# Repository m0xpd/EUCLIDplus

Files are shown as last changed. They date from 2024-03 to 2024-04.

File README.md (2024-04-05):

# EUCLID+
EUCLID+ is a novel Clock Divider, Clock Multiplier and Rhythm Sequencer for electronic music applications. 

<p width=100%, align="center">
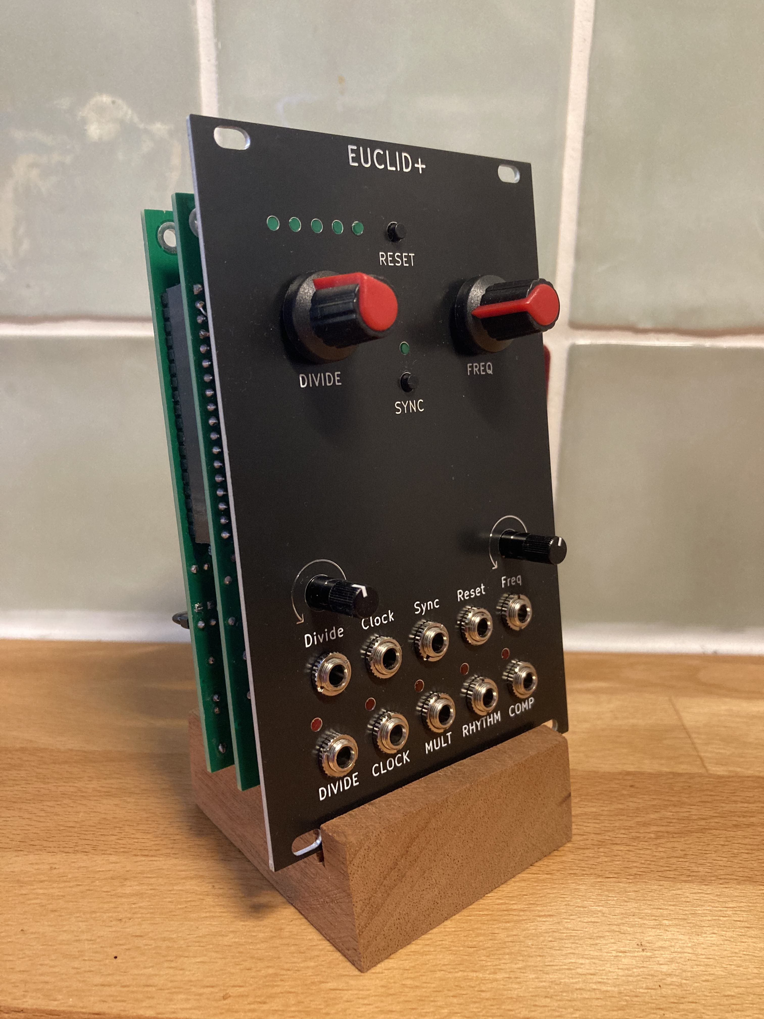
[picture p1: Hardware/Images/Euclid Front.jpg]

</p>

EUCLID+ builds gate patterns, including [Euclidean Rhythms.](https://en.wikipedia.org/wiki/Euclidean_rhythm) Unlike most instances of Euclidean Rhythms, which are generated by algorithms, EUCLID+ is realised entirely in hardware and builds its patterns using what I shall call [conditional modulation](https://github.com/m0xpd/EUCLIDplus/tree/main/Operation#readme) of an external clock signal by the signal from an oscillator internal to EUCLID+.

Strictly speaking, EUCLID+ *usually* produces a *rotation* of a Euclidean Rhythm (which is an instance of the same '[rhythm necklace](https://cgm.cs.mcgill.ca/~godfried/publications/banff.pdf)' as the Euclidean Rhythm). EUCLID+ *occasionally* produces a Euclidean Rhythm.

If you're looking for a module where you just dial in parameters and out pops a Euclidean Rhythm, this isn't for you. However, if you're interested in working with a creative platform on which you can explore possibilities in rhythm generation, and are open to the surprises which you meet along the way, EUCLID+ might be of interest. 

Here's a 'scope trace of EUCLID+ producing the [tresillo](https://en.wikipedia.org/wiki/Tresillo_(rhythm)) (or habanera) rhythm, which is Euclidean Rhythm "*E*(3,8)" (= [10010010] or, as more frequently represented in the notation used in musicology, [x..x..x.]).

<p width=100%, align="center">
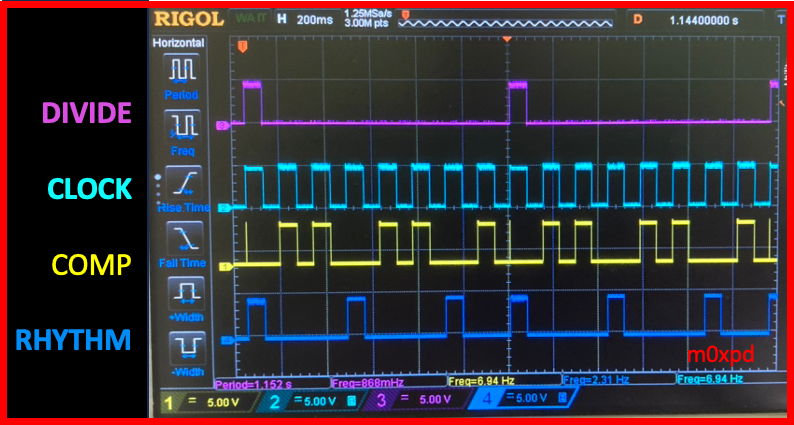
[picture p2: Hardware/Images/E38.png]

</p>

There are more examples of EUCLID+ performance [here](https://github.com/m0xpd/EUCLIDplus/blob/main/Operation/README.md#performance-examples).

EUCLID+ divides an applied clock signal by any integer divisor up to 30, making EUCLID+ useful as a voltage-controlled hardware clock divider. The start of the clock divide cycle can be reset manually, using the RESET pushbutton, or under CV control via the Reset input.

EUCLID+ includes an integral VCO, operating in the LFO range, which can serve as a voltage controlled clock multiplier. Signals from the clock divider and clock multiplier are available for external use on the DIVIDE and MULT outputs. 

EUCLID+ combines the clock input and the signal from the clock multiplier to provide gate patterns on the RHYTHM output. The complements of these patterns appear on the COMP output. The duty cycle of the RHYTHM and COMP outputs follows that of the input Clock waveform.

EUCLID+ can hard-sync its VCO to the clock divider output. In this condition, the output pattern is fixed, having the same period as the clock divider. The patterns in this synchronous mode include the familiar [Euclidean Rhythms](https://en.wikipedia.org/wiki/Euclidean_rhythm) (of length up to 30). Note that [the complement of a Euclidean Rhythm is itself Euclidean](https://www.researchgate.net/publication/228841028_Interlocking_and_Euclidean_rhythms); the COMP output produces musically useful triggers for primary voices in complementary and interlocking rhythmic structures as well as for producing "ghost notes".

Alternatively, the VCO inside EUCLID+ can run asynchronously to the applied clock, giving the resulting pattern outputs a useful varying quality, but one which retains much of the structure (/correlation/'feel') of the behaviour in synchronous mode. Careful tuning of the VCO in asynchronous mode can exploit this variation to impart slow, organic change into what can otherwise be a dry, sterile, mechanistic process.

Switching between synchronous and asynchronous operation can be achieved manually, using the SYNC pushbutton, or under CV control via the Sync input.

There is a fuller description of the principles behind EUCLID+ operation [here](https://github.com/m0xpd/EUCLIDplus/tree/main/Operation#readme) and a detailed description of circuit operation [here](https://github.com/m0xpd/EUCLIDplus/tree/main/Operation#circuit-description).

The Clock Divider's DIVIDE setting is reported on five LEDs at the top left of the front panel. There are two idosyncracies of this display worth explaining. 

First, the binary display is arranged with least significant bit on the left, which (of course) is opposite to ordinary practice. This reversal was adopted as it made the display more 'natural' in use, given its placement immediately above the DIVIDE potentiometer, which generates an increasing value as it is rotated clockwise. 

Second, as explained in the [description of system operation](https://github.com/m0xpd/EUCLIDplus/tree/main/Operation#readme), the binary number on the display must be set to one greater than the desired clock divisor. In other words, to achieve a clock division of 8, you must set the number 9 (1,0,0,1) on the LEDs.  

Full design details for EUCLID+ including schematics, PCB layouts for the [Main Board](https://github.com/m0xpd/EUCLIDplus/tree/main/Hardware/Main%20Board#readme) and [Control Board](https://github.com/m0xpd/EUCLIDplus/tree/main/Hardware/Control%20Board#readme) and a [Front Panel](https://github.com/m0xpd/EUCLIDplus/tree/main/Hardware/Front%20Panel#readme) design, are presented in the hardware folder.  

For those who are discouraged by the complexity of the hardware approach - or those who would simply like to play with the rhythm generation method used in EUCLID+ in a context which avoids oscillator drift and the other non-ideal behaviours associated with hardware - a software implementation of EUCLID+ is presented [here](https://github.com/m0xpd/EUCLIDplus/tree/main/Software%20Version#readme)

# Introductory Video

A [simple video](https://youtu.be/RWJx1ux7fJk) demonstrates some of the basic functionalty of EUCLID+

# License

EUCLID+ (including the descriptions of its operating principles, and the hardware and software embodiments described in this repository) is published under [CC BY-SA 4.0 License](https://github.com/m0xpd/EUCLIDplus/blob/main/LICENSE.txt).

# Specifications

**Width:** 

EUCLID+ is **16HP wide**.

**Depth:**

EUCLID+ extends **43 mm** behind the front panel when a conventional Eurorack power header **with strain relief** is inserted 

If your power header doesn't have a strain relief (which is probably more typical, judging by the power cables delivered with commercial modules) EUCLID+ extends **37 mm** behind the front panel.

**Power Consumption:**

| Power Rail | Current |
|---|---|
| +12V | **30mA** | 
| -12V | **15mA** |
| 5V | **0** |

The 12V current drain was fluctuating during measurement (with the module's switching behaviour during operation and during operation of the controls); the 30mA figure quoted above is an 'eyeball estimate' of average current - the peak drain observed was 35mA.
The -12V current drain was steady; 15mA is the average consumption.

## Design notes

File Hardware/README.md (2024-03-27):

# Hardware
This folder contains details of the hardware of the Euclid+ Rhythm Generator.

There is a [Front Panel](https://github.com/m0xpd/EUCLIDplus/tree/main/Hardware/Front%20Panel#readme), Defined by a KiCad project, and two PCBs - the [Main Board](https://github.com/m0xpd/EUCLIDplus/tree/main/Hardware/Main%20Board#readme) and the [Control Board](https://github.com/m0xpd/EUCLIDplus/tree/main/Hardware/Control%20Board#readme).

Schematics for the boards, as graphics, are presented in the [circuit description](https://github.com/m0xpd/EUCLIDplus/tree/main/Operation#readme) (and are available within the KiCad projects).

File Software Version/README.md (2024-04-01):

# EUCLID+ in Software

This folder describes a software implementation of the principles behind EUCLID+

There is a basic coding of the EUCLID+ method in Python [here](https://github.com/m0xpd/EUCLIDplus/blob/main/Software%20Version/EuclidPlus.py), intended to run on the [Raspberry Pi PICO](https://www.raspberrypi.com/products/raspberry-pi-pico/). It could easily be ported to other RPi-based platforms, such as [EuroPi](https://allensynthesis.co.uk/modules/europi.html). 

The code certainly isn't pretty - I hacked it from a Ratcheting clock multiplier application I had been playing with, so many of the variable names and the overall structure didn't start on a blank canvas, which would have been better practice. However, it does the job.

I have also sketched a partial KiCad project showing how the code could be supported by hardware which could easily be elaborated into a module. Most importantly, there's a [.sch file](https://github.com/m0xpd/EUCLIDplus/blob/main/Software%20Version/Platform/EuclidPlusPi.kicad_sch) and a (graphical) schematic...

<p width=100%, align="center">

</p>

The code and hardware were validated at breadboard level on a simple system, shown below:

<p width=100%, align="center">
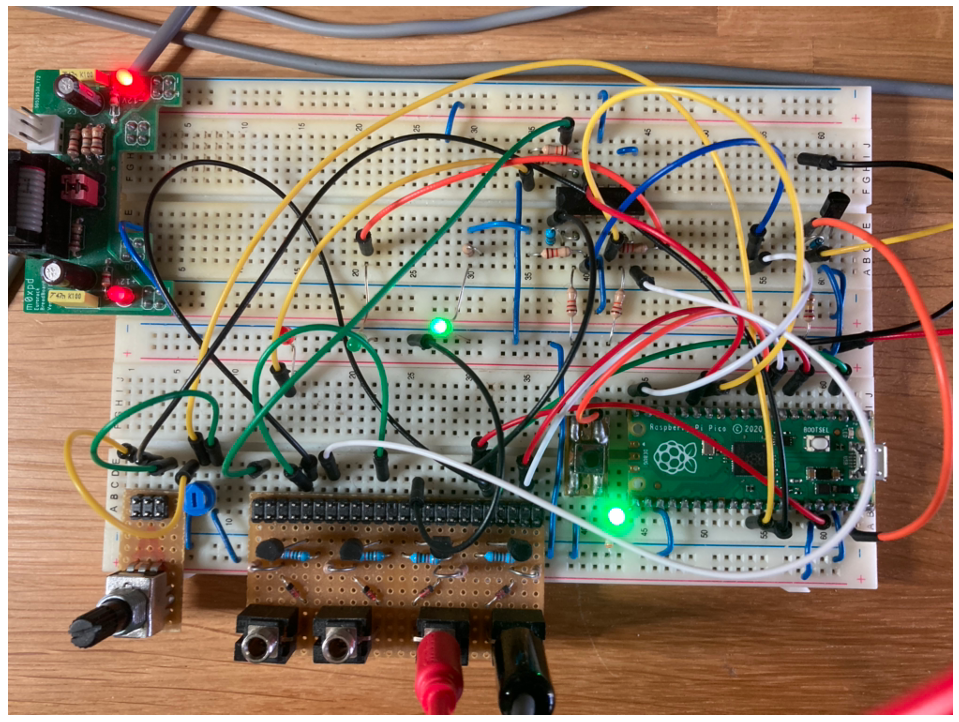
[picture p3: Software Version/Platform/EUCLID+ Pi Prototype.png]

</p>

The example system and its circuitry include only manual controls (for clock division, internal oscillator frequency, etc) with no provision for Voltage Control. CV inputs could readily be included using standard methods, such as those used in the EUCLID+ module, appropriately adapted for the (0:3V3) operating range of the RPi.

The pin allocation for the RPi is shown below:

<p width=100%, align="center">
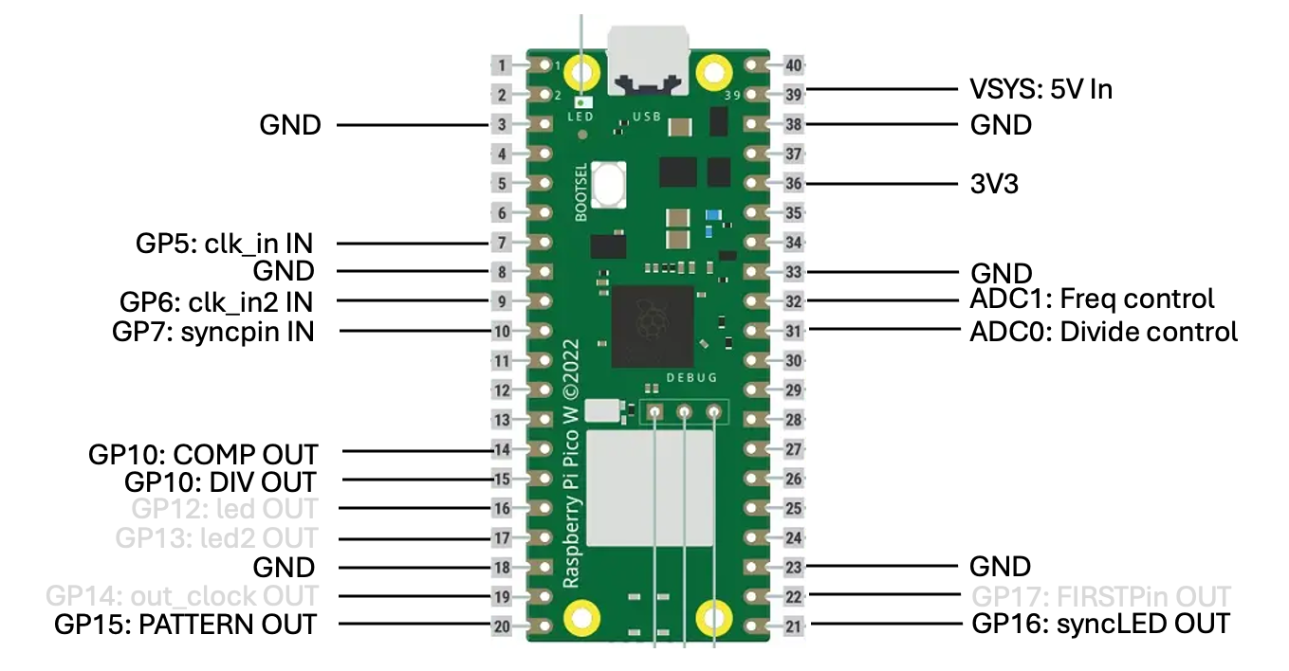
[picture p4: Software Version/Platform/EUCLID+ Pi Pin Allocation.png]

</p>

Notice that I originally named the main 'RHYTHM' output of EUCLID+ 'PATTERN'. Apologies for this (and any other) notational anomaly.

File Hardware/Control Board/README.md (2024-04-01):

# Control Board
This folder contains details of the EUCLID+ Control Board.

<p width=100%, align="center">
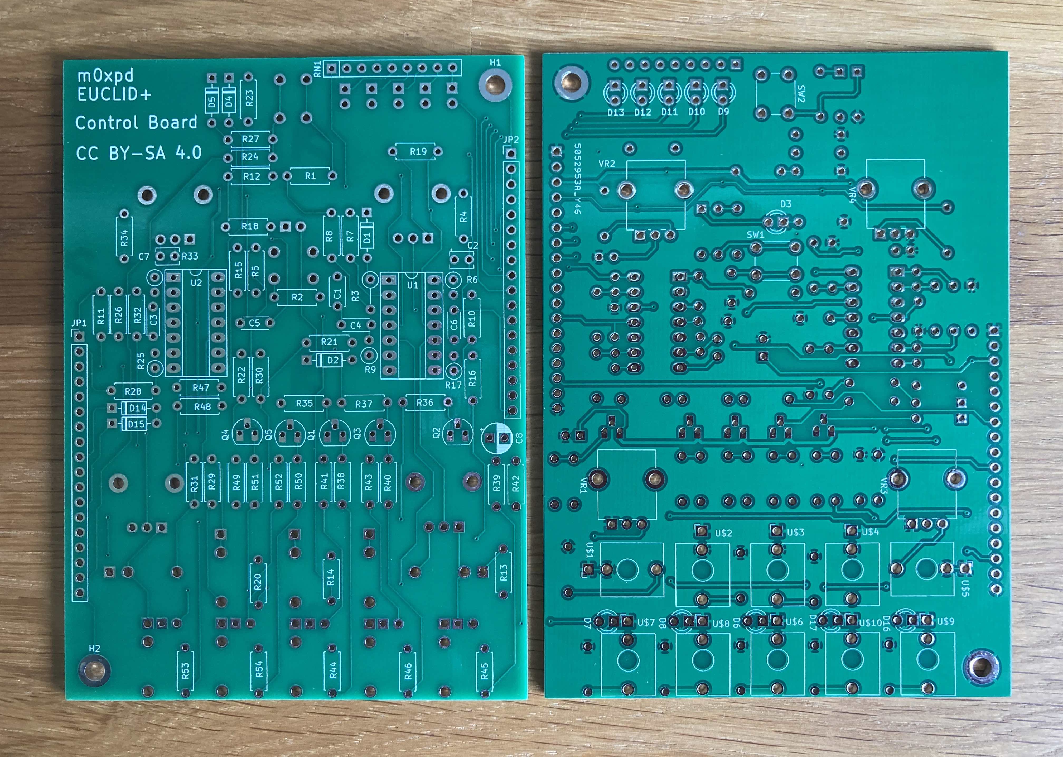
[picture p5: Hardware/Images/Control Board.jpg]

</p>

[This is actually a photo of the v1 Control Board. This earlier version had a different slightly footprint for C8, which is now a radial electrolytic. Also, some of the PCB tracks carrying power on the v2 version are thicker than on the V1 version, which is archived in the [v1 Control Board](https://github.com/m0xpd/EUCLIDplus/tree/main/Hardware/Control%20Board/v1%20Control%20Board) folder]

The populated (v1) Control Board is seen (from the top/component side) in the photo below. It is mounted to the [Front Panel](https://github.com/m0xpd/EUCLIDplus/tree/main/Hardware/Front%20Panel#readme) by the two (9mm Alpha) potentiometers and the ten ("Thonkiconn") sockets mounted on the bottom side.

<p width=100%, align="center">
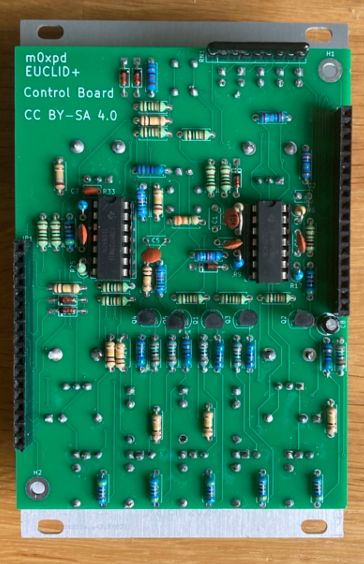
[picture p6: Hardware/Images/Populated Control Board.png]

</p>

Also visible in the image above are the two 1*18 0.1 inch headers which join the Main and Control boards electrically. These are female headers on the top of the Control Board, which mate with corresponding male headers on the bottom of the Main Board. These headers provide sufficient mechanical mounting of the two boards for 'static' applications, but there are provided two 3mm clearance mounting holes, H1 & H2, to make a more robust assembly with M3 screws and spacers, if required.

This folder contains a KiCad [Project File (.pro)](https://github.com/m0xpd/EUCLIDplus/blob/main/Hardware/Control%20Board/Euclid%2B%20Control%20Board.kicad_pro), a [Schematic File (.sch)](https://github.com/m0xpd/EUCLIDplus/blob/main/Hardware/Control%20Board/Euclid%2B%20Control%20Board.kicad_sch) and a [PCB file (.pcb)](https://github.com/m0xpd/EUCLIDplus/blob/main/Hardware/Control%20Board/Euclid%2B%20Control%20Board.kicad_pcb).

There is also a [BoM](https://github.com/m0xpd/EUCLIDplus/blob/main/Hardware/Control%20Board/Euclid%2B%20Control%20Board%20BoM.xlsx), which is an Excel file; you will have to download the raw file and view it outside github.

A version of the schematic in graphical (svg) format is available in the [Operation](https://github.com/m0xpd/EUCLIDplus/tree/main/Operation#readme) folder

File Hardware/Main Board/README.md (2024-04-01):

# Main Board
This folder contains details of the EUCLID+ Main Board.

<p width=100%, align="center">
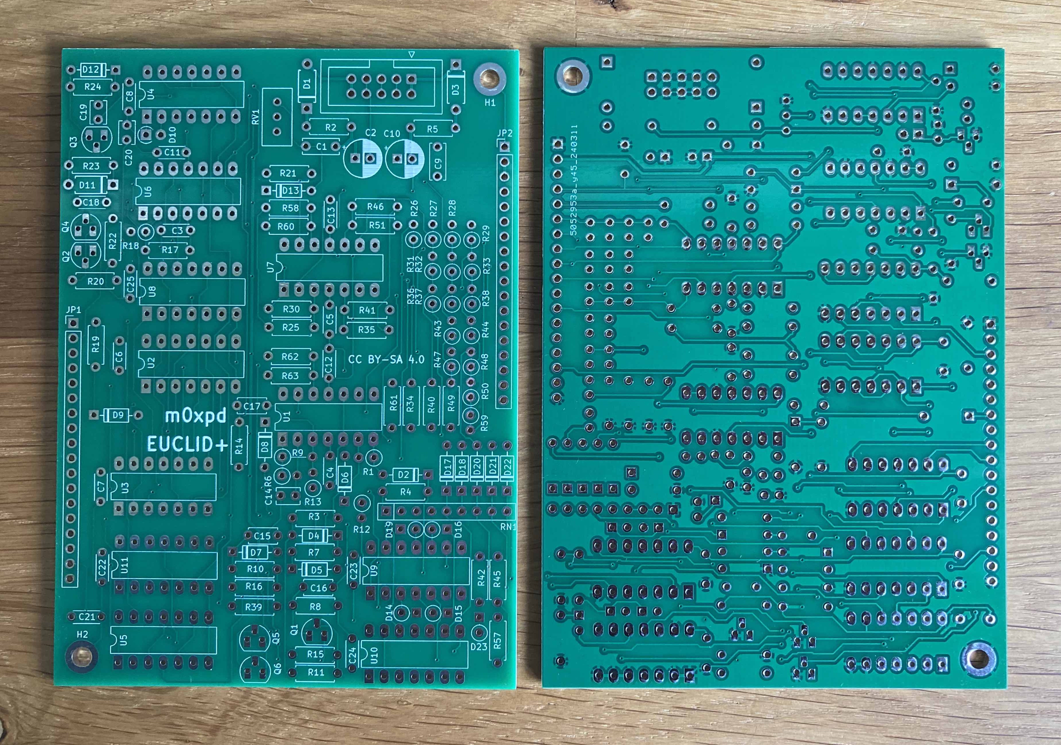
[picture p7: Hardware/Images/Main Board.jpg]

</p>

[This is actually a photo of the v1 Main Board, which had some errors on the bottom side - the project associated with this board is in the [v1 Main Board folder](https://github.com/m0xpd/EUCLIDplus/tree/main/Hardware/Main%20Board/v1%20Main%20Board) and the errors are indicated on the schematic. This v1 Main Board also does not include the footprint for C28, which was found necessary to avoid jitter on the internal oscillator signal's duty cycle.]

Here's the populated (v1) Main Board, seen from the component side:
<p width=100%, align="center">
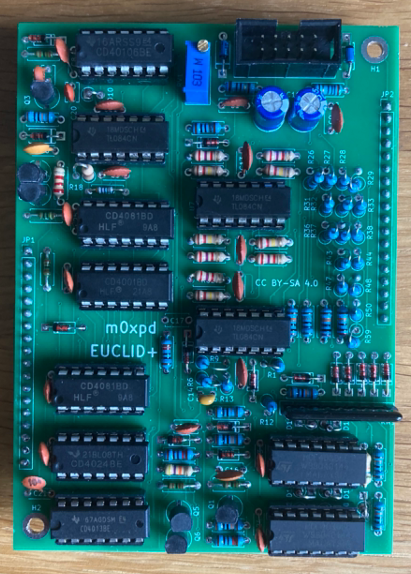
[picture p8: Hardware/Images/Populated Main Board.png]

</p>

The folder contains a KiCad [Project File (.pro)](https://github.com/m0xpd/EUCLIDplus/blob/main/Hardware/Main%20Board/Euclid%2B%20Main%20Board.kicad_pro), a [Schematic File (.sch)](https://github.com/m0xpd/EUCLIDplus/blob/main/Hardware/Main%20Board/Euclid%2B%20Main%20Board.kicad_sch) and a [PCB file (.pcb)](https://github.com/m0xpd/EUCLIDplus/blob/main/Hardware/Main%20Board/Euclid%2B%20Main%20Board.kicad_pcb).

There is also a [BoM](https://github.com/m0xpd/EUCLIDplus/blob/main/Hardware/Main%20Board/Euclid%2B%20Main%20Board%20BoM.xlsx) which is an Excel file; you will have to download the raw file and view it outside github. 

A version of the schematic in graphical (svg) format is available in the [Operation](https://github.com/m0xpd/EUCLIDplus/tree/main/Operation#readme) folder

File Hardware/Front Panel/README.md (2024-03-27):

# Front Panel
This folder contains details of the EUCLID+ Front Panel.

<p width=100%, align="center">
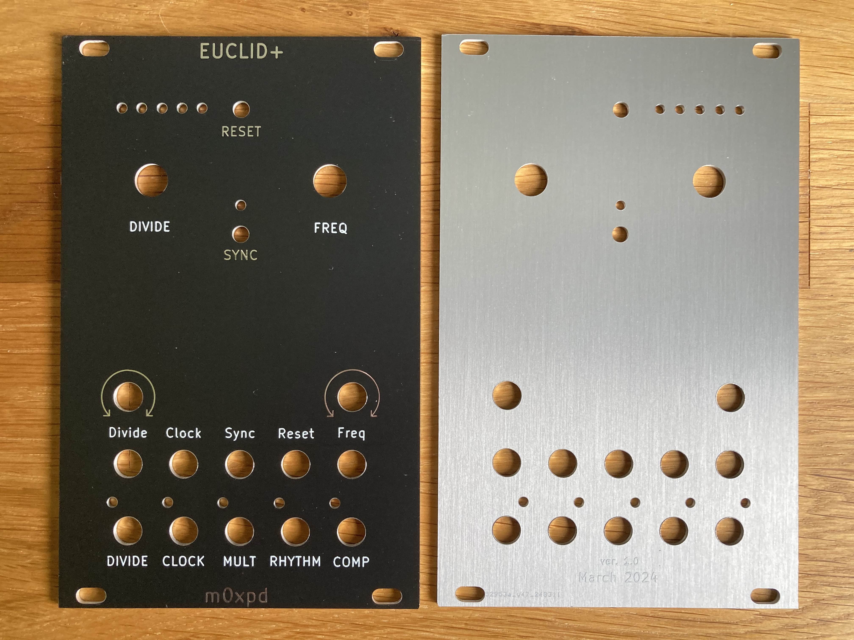
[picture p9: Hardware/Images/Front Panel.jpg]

</p>

There is a KiCad Project File (.pro), a Schematic File (.sch) - although this is empty, as the Front Panel is electrically inactive (it is required only to make a valid project). Most importantly, 
there is a PCB file (.pcb).

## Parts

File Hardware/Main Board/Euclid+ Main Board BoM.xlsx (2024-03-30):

Source: | /Users/pauldarlington/Documents/Analog Synth/Euclid/Euclid+ Main Board/Euclid+ Main Board.kicad_sch
Date: | Wednesday, March 27, 2024 at 01:09:04‚ÄØPM
Tool: | Eeschema 7.0.9
Generator: | /Applications/KiCad/KiCad.app/Contents/SharedSupport/plugins/bom_csv_grouped_by_value.py
Component Count: | 130
Collated Components:
Item | Qty | Reference(s) | Value | Orientation | LibPart | Footprint | Datasheet | DNP | Sim.Device | Sim.Pins
1 | 2 | C1, C9 | 0.1u |  | main board-eagle-import:C-EU050-025X075 | Capacitor_THT:C_Disc_D6.0mm_W2.5mm_P5.00mm
2 | 2 | C2, C10 | 22u |  | Device:C_Polarized | Capacitor_THT:CP_Radial_D6.3mm_P2.50mm | ~
3 | 14 | C3, C4, C5, C6, C7, C8, C11, C12, C13, C21, C22, C23, C24, C25 | 100n |  | Device:C | Capacitor_THT:C_Disc_D4.3mm_W1.9mm_P5.00mm | ~
4 | 4 | C14, C15, C16, C17 | 100n |  | Device:C | Capacitor_THT:C_Disc_D4.7mm_W2.5mm_P5.00mm | ~
5 | 1 | C18 | 2n2 |  | Device:C | Capacitor_THT:C_Disc_D4.3mm_W1.9mm_P5.00mm | ~
6 | 1 | C19 | 4n7 |  | Device:C | Capacitor_THT:C_Disc_D3.8mm_W2.6mm_P2.50mm | ~
7 | 1 | C20 | 10n |  | Device:C | Capacitor_THT:C_Disc_D3.8mm_W2.6mm_P2.50mm | ~
8 | 1 | C26 | 1u |  | Device:C | Capacitor_THT:CP_Radial_D6.3mm_P2.50mm
9 | 2 | D1, D3 | BAT42 | Horizontal | Device:D_Schottky_Small | Diode_THT:D_A-405_P7.62mm_Horizontal | ~
10 | 14 | D2, D4, D5, D6, D7, D8, D9, D12, D13, D17, D18, D20, D21, D22 | 1N4148 | Horizontal | Diode:1N4148 | Diode_THT:D_DO-35_SOD27_P7.62mm_Horizontal | https://assets.nexperia.com/documents/data-sheet/1N4148_1N4448.pdf |  | D | 1=K 2=A
11 | 1 | D10 | 1N4148 | Vertical | Diode:1N4148 | Diode_THT:D_A-405_P2.54mm_Vertical_AnodeUp | https://assets.nexperia.com/documents/data-sheet/1N4148_1N4448.pdf |  | D | 1=K 2=A
12 | 1 | D11 | 1N4148 | Horizontal | Diode:1N4148 | Diode_THT:D_A-405_P7.62mm_Horizontal | https://assets.nexperia.com/documents/data-sheet/1N4148_1N4448.pdf |  | D | 1=K 2=A
13 | 5 | D14, D15, D16, D19, D23 | 1N4148 | Vertical | Diode:1N4148 | Diode_THT:D_DO-35_SOD27_P2.54mm_Vertical_KathodeUp | https://assets.nexperia.com/documents/data-sheet/1N4148_1N4448.pdf |  | D | 1=K 2=A
14 | 2 | H1, H2 | MountingHole_Pad |  | Mechanical:MountingHole_Pad | MountingHole:MountingHole_3.2mm_M3_DIN965_Pad_TopBottom | ~
15 | 2 | JP1, JP2 | ~ |  | control board-eagle-import:PINHD-1X18 | Connector_PinHeader_2.54mm:PinHeader_1x18_P2.54mm_Vertical
16 | 5 | Q1, Q2, Q3, Q5, Q6 | BC546 |  | Transistor_BJT:BC546 | Package_TO_SOT_THT:TO-92_HandSolder | https://www.onsemi.com/pub/Collateral/BC550-D.pdf
17 | 1 | Q4 | BC556 |  | Transistor_BJT:BC556 | Package_TO_SOT_THT:TO-92_HandSolder | https://www.onsemi.com/pub/Collateral/BC556BTA-D.pdf
18 | 9 | R1, R6, R26, R31, R32, R33, R43, R44, R50 | 100k | Vertical | Device:R | Resistor_THT:R_Axial_DIN0207_L6.3mm_D2.5mm_P2.54mm_Vertical | ~
19 | 2 | R2, R5 | 10R | Horizontal | main board-eagle-import:R-EU_0204/7 | Resistor_THT:R_Axial_DIN0207_L6.3mm_D2.5mm_P7.62mm_Horizontal
20 | 8 | R3, R4, R7, R15, R23, R34, R45, R57 | 100k | Horizontal | Device:R | Resistor_THT:R_Axial_DIN0207_L6.3mm_D2.5mm_P7.62mm_Horizontal | ~
21 | 4 | R8, R19, R24, R39 | 22k | Horizontal | Device:R | Resistor_THT:R_Axial_DIN0207_L6.3mm_D2.5mm_P7.62mm_Horizontal | ~
22 | 1 | R9 | 10k | Vertical | Device:R | Resistor_THT:R_Axial_DIN0207_L6.3mm_D2.5mm_P5.08mm_Vertical | ~
23 | 3 | R10, R11, R14 | 10k | Horizontal | Device:R | Resistor_THT:R_Axial_DIN0207_L6.3mm_D2.5mm_P7.62mm_Horizontal | ~
24 | 2 | R12, R13 | 10k | Vertical | Device:R | Resistor_THT:R_Axial_DIN0207_L6.3mm_D2.5mm_P2.54mm_Vertical | ~
25 | 1 | R16 | 47k | Horizontal | Device:R | Resistor_THT:R_Axial_DIN0207_L6.3mm_D2.5mm_P7.62mm_Horizontal | ~
26 | 1 | R17 | 11k | Horizontal | Device:R | Resistor_THT:R_Axial_DIN0207_L6.3mm_D2.5mm_P7.62mm_Horizontal | ~
27 | 1 | R18 | 12k | Vertical | Device:R | Resistor_THT:R_Axial_DIN0207_L6.3mm_D2.5mm_P2.54mm_Vertical | ~
28 | 1 | R20 | 1M | Horizontal | Device:R | Resistor_THT:R_Axial_DIN0207_L6.3mm_D2.5mm_P7.62mm_Horizontal | ~
29 | 1 | R21 | 1k | Horizontal | Device:R | Resistor_THT:R_Axial_DIN0207_L6.3mm_D2.5mm_P7.62mm_Horizontal | ~
30 | 1 | R22 | 2K2 | Horizontal | Device:R | Resistor_THT:R_Axial_DIN0207_L6.3mm_D2.5mm_P7.62mm_Horizontal | ~
31 | 5 | R25, R35, R46, R58, R62 | 2k7 | Horizontal | Device:R | Resistor_THT:R_Axial_DIN0207_L6.3mm_D2.5mm_P7.62mm_Horizontal | ~
32 | 9 | R27, R28, R29, R36, R37, R38, R47, R48, R59 | 200k | Vertical | Device:R | Resistor_THT:R_Axial_DIN0207_L6.3mm_D2.5mm_P2.54mm_Vertical | ~
33 | 5 | R30, R41, R51, R60, R63 | 120k | Horizontal | Device:R | Resistor_THT:R_Axial_DIN0207_L6.3mm_D2.5mm_P7.62mm_Horizontal | ~
34 | 3 | R40, R49, R61 | 200k | Horizontal | Device:R | Resistor_THT:R_Axial_DIN0207_L6.3mm_D2.5mm_P7.62mm_Horizontal | ~
35 | 1 | R42 | 56k | Horizontal | Device:R | Resistor_THT:R_Axial_DIN0207_L6.3mm_D2.5mm_P7.62mm_Horizontal | ~
36 | 1 | RN1 | 10k |  | Device:R_Network08 | Resistor_THT:R_Array_SIP9 | http://www.vishay.com/docs/31509/csc.pdf
37 | 1 | RV1 | 10k |  | Device:R_Potentiometer_Trim | Potentiometer_THT:Potentiometer_Bourns_3296W_Vertical | ~
38 | 3 | U1, U6, U7 | TL084 |  | Amplifier_Operational:TL084 | Package_DIP:DIP-14_W7.62mm_LongPads | http://www.ti.com/lit/ds/symlink/tl081.pdf
39 | 1 | U2 | 4001 |  | 4xxx:4001 | Package_DIP:DIP-14_W7.62mm_LongPads | http://www.intersil.com/content/dam/Intersil/documents/cd40/cd4000bms-01bms-02bms-25bms.pdf
40 | 2 | U3, U8 | 4081 |  | 4xxx:4081 | Package_DIP:DIP-14_W7.62mm_LongPads | http://www.intersil.com/content/dam/Intersil/documents/cd40/cd4073bms-81bms-82bms.pdf
41 | 1 | U4 | 40106 |  | 4xxx:40106 | Package_DIP:DIP-14_W7.62mm_LongPads | https://assets.nexperia.com/documents/data-sheet/HEF40106B.pdf
42 | 1 | U5 | 4013 |  | 4xxx:4013 | Package_DIP:DIP-14_W7.62mm_LongPads | http://www.onsemi.com/pub/Collateral/MC14013B-D.PDF
43 | 2 | U9, U10 | 4030 |  | 4xxx_IEEE:4030 | Package_DIP:DIP-14_W7.62mm_LongPads
44 | 1 | U11 | 4024 |  | 4xxx_IEEE:4024 | Package_DIP:DIP-14_W7.62mm_LongPads
45 | 1 | X1 | 2510- |  | main board-eagle-import:2510- | Connector_IDC:IDC-Header_2x05_P2.54mm_Vertical

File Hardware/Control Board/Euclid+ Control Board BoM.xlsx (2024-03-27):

Source: | /Users/pauldarlington/Documents/Analog Synth/Euclid/Euclid+ Control Board/Euclid+ Control Board.kicad_sch
Date: | Wednesday, March 27, 2024 at 01:17:49‚ÄØPM
Tool: | Eeschema 7.0.9
Generator: | /Applications/KiCad/KiCad.app/Contents/SharedSupport/plugins/bom_csv_grouped_by_value.py
Component Count: | 107
Collated Components:
Item | Qty | Reference(s) | Value | Orientation | LibPart | Footprint | Datasheet | DNP | Sim.Device | Sim.Pins
1 | 1 | C1 | 100n |  | Device:C | Capacitor_THT:C_Disc_D4.7mm_W2.5mm_P5.00mm | ~
2 | 2 | C2, C8 | 1u |  | Device:C_Polarized_Small | Capacitor_THT:CP_Radial_D5.0mm_P2.50mm | ~
3 | 4 | C3, C4, C5, C6 | 100n |  | Device:C | Capacitor_THT:C_Disc_D4.3mm_W1.9mm_P5.00mm | ~
4 | 1 | C7 | 10n |  | Device:C | Capacitor_THT:C_Disc_D3.8mm_W2.6mm_P2.50mm | ~
5 | 6 | D1, D2, D4, D5, D14, D15 | 1N4148 |  | Diode:1N4148 | Diode_THT:D_DO-35_SOD27_P7.62mm_Horizontal | https://assets.nexperia.com/documents/data-sheet/1N4148_1N4448.pdf |  | D | 1=K 2=A
6 | 11 | D3, D6, D7, D8, D9, D10, D11, D12, D13, D16, D17 | LED |  | Device:LED | LED_THT:LED_D3.0mm | ~
7 | 2 | H1, H2 | MountingHole_Pad |  | Mechanical:MountingHole_Pad | MountingHole:MountingHole_3.2mm_M3_DIN965_Pad_TopBottom | ~
8 | 2 | JP1, JP2 | ~ |  | control board-eagle-import:PINHD-1X18 | Connector_PinHeader_2.54mm:PinHeader_1x18_P2.54mm_Vertical
9 | 5 | Q1, Q2, Q3, Q4, Q5 | BC546 |  | Transistor_BJT:BC546 | Package_TO_SOT_THT:TO-92_HandSolder | https://www.onsemi.com/pub/Collateral/BC550-D.pdf
10 | 13 | R1, R7, R8, R10, R11, R12, R26, R27, R35, R36, R37, R47, R48 | 10k | Horizontal | Device:R | Resistor_THT:R_Axial_DIN0207_L6.3mm_D2.5mm_P7.62mm_Horizontal | ~
11 | 1 | R2 | 3M3 | Horizontal | Device:R | Resistor_THT:R_Axial_DIN0207_L6.3mm_D2.5mm_P7.62mm_Horizontal | ~
12 | 1 | R3 | 220k | Vertical | Device:R | Resistor_THT:R_Axial_DIN0207_L6.3mm_D2.5mm_P5.08mm_Vertical | ~
13 | 2 | R4, R19 | 270k | Horizontal | Device:R | Resistor_THT:R_Axial_DIN0207_L6.3mm_D2.5mm_P7.62mm_Horizontal | ~
14 | 9 | R5, R13, R14, R20, R22, R24, R28, R29, R31 | 100k | Horizontal | Device:R | Resistor_THT:R_Axial_DIN0207_L6.3mm_D2.5mm_P7.62mm_Horizontal | ~
15 | 1 | R6 | 56k | Vertical | Device:R | Resistor_THT:R_Axial_DIN0207_L6.3mm_D2.5mm_P2.54mm_Vertical | ~
16 | 1 | R9 | 100k | Vertical | Device:R | Resistor_THT:R_Axial_DIN0207_L6.3mm_D2.5mm_P2.54mm_Vertical | ~
17 | 3 | R15, R21, R30 | 15k | Horizontal | Device:R | Resistor_THT:R_Axial_DIN0207_L6.3mm_D2.5mm_P7.62mm_Horizontal | ~
18 | 2 | R16, R32 | 47k | Horizontal | Device:R | Resistor_THT:R_Axial_DIN0207_L6.3mm_D2.5mm_P7.62mm_Horizontal | ~
19 | 2 | R17, R33 | 47k | Vertical | Device:R | Resistor_THT:R_Axial_DIN0207_L6.3mm_D2.5mm_P2.54mm_Vertical | ~
20 | 6 | R18, R41, R42, R43, R51, R52 | 5k6 | Horizontal | Device:R | Resistor_THT:R_Axial_DIN0207_L6.3mm_D2.5mm_P7.62mm_Horizontal | ~
21 | 1 | R23 | 1k | Horizontal | Device:R | Resistor_THT:R_Axial_DIN0207_L6.3mm_D2.5mm_P7.62mm_Horizontal | ~
22 | 1 | R25 | 10k | Vertical | Device:R | Resistor_THT:R_Axial_DIN0207_L6.3mm_D2.5mm_P2.54mm_Vertical | ~
23 | 1 | R34 | 180k | Horizontal | Device:R | Resistor_THT:R_Axial_DIN0207_L6.3mm_D2.5mm_P7.62mm_Horizontal | ~
24 | 5 | R38, R39, R40, R49, R50 | 1k2 | Horizontal | Device:R | Resistor_THT:R_Axial_DIN0207_L6.3mm_D2.5mm_P7.62mm_Horizontal | ~
25 | 5 | R44, R45, R46, R53, R54 | 4k7 | Horizontal | Device:R | Resistor_THT:R_Axial_DIN0207_L6.3mm_D2.5mm_P7.62mm_Horizontal | ~
26 | 1 | RN1 | 10k |  | Device:R_Network08 | Resistor_THT:R_Array_SIP9 | http://www.vishay.com/docs/31509/csc.pdf
27 | 2 | SW1, SW2 | SW_Push |  | Switch:SW_Push | Button_Switch_THT:SW_PUSH_6mm_H13mm | ~
28 | 2 | U1, U2 | TL084 |  | Amplifier_Operational:TL084 | Package_DIP:DIP-14_W7.62mm_Socket_LongPads | http://www.ti.com/lit/ds/symlink/tl081.pdf
29 | 10 | U$1, U$2, U$3, U$4, U$5, U$6, U$7, U$8, U$9, U$10 | THONKICONN_JACK |  | Connector_Audio:AudioJack2_SwitchT | Connector_Audio:Jack_3.5mm_QingPu_WQP-PJ398SM_Vertical_CircularHoles | ~
30 | 2 | VR2, VR4 | B100k |  | Alpha 9mm Vertical Pot | Potentiometer_THT:Potentiometer_Alpha_RD901F-40-00D_Single_Vertical_CircularHoles
31 | 2 | VR1, VR3 | B100k |  | Song Huei 9mm Trimpot | Potentiometer_THT:Potentiometer_Alpha_RD901F-40-00D_Single_Vertical_CircularHoles

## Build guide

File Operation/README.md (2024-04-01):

# EUCLID+ Operation

This section contains a description of the principles behind EUCLID+ and a detailed description of the implementation of these principles in the EUCLID+ module's electronic circuits.

A [defining property](https://cgm.cs.mcgill.ca/~godfried/publications/banff.pdf) of Euclidean Rhythms (*E*'s) is the fact that an *E* of length L having N onsets represents the most even distribution of the N onsets over L beats.

This led me to investigate the idea of setting a switching waveform of period L/x against the period, L, where x is continuously variable. When x is a simple positive integer 
(1, 2, 3, ...) this just gives a exact number of periods of the internal oscillator for every period, L, and will identify the perfect division of L into x sections.

If we could identify the FIRST of the clock pulses which occur in each of these sections, we shall have found the most even distribution of x pulses - 
a Euclidean Rhythm of Length = L and Number of Onsets or 'Density' = x, *E*(x,L).

For example, the graphic below shows an idealised Clock signal and the internal oscilator signal, 'Osc', set to L = 8, x = 3

<p width=100%, align="center">
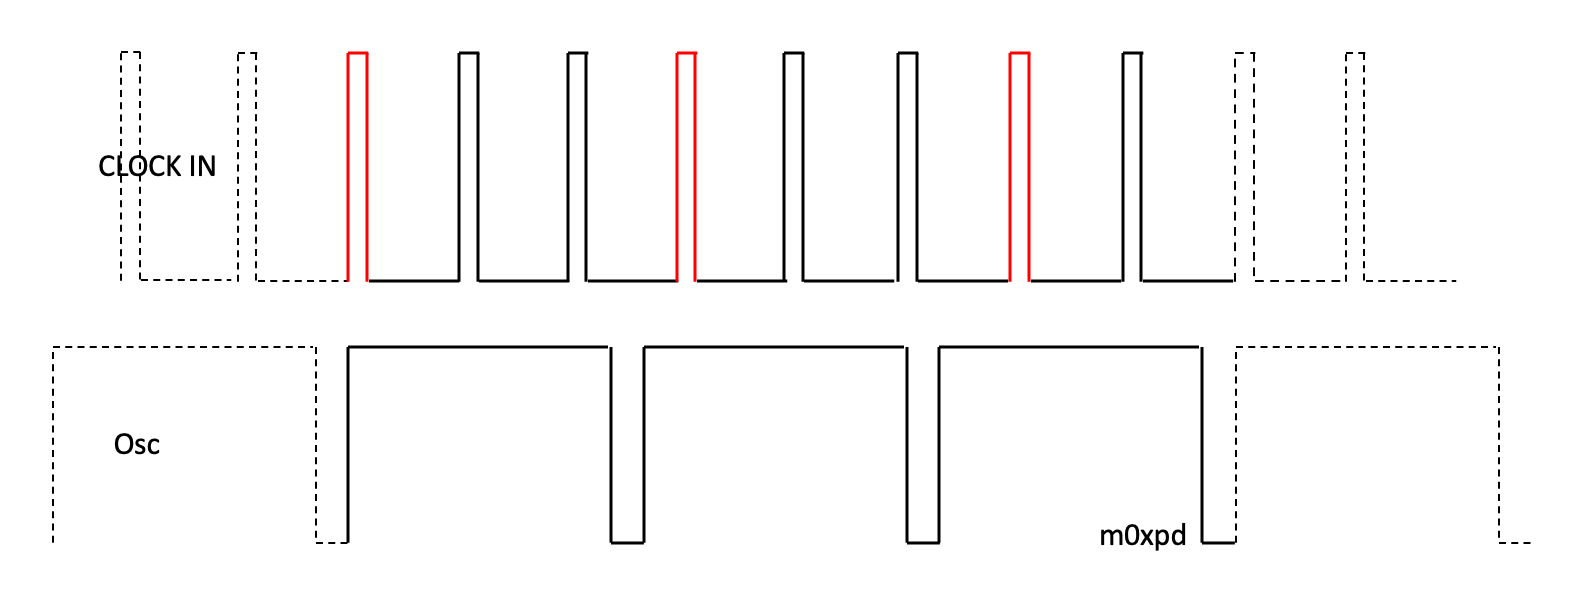
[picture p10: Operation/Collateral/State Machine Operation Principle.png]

</p>

The first clock pulse within each period of the 'Osc' signal is identified in red - readers familiar with Euclidean Rhythms will recognise the result as a valid *E*(3,8) - in fact, it is the famous Cuban [*tresillo*](https://en.wikipedia.org/wiki/Tresillo_(rhythm)) rhythm. There's a 'scope trace of EUCLID+ producing the tresillo on the [Front Page](https://github.com/m0xpd/EUCLIDplus/tree/main#).

This is what EUCLID+ does - it takes the incoming clock signal and turns it into a pulse train at the clock leading edge (using a one-shot/monostable around U1A) 
and generates a high duty cycle signal, 'Osc', from the internal VCO. The first clock pulse in every period of the VCO signal is identified by the signal FIRST, which is held on a 
S-R flip-flop (implemented on gates A and B of U2&3). When FIRST is true, the output is set when both the internal oscillator (Osc) and the clock are true (i.e. the system just ANDs 
the clock and internal oscillator together for the first pulse). HOWEVER, for subsequent clock pulses (when FIRST is false) no output is produced. 

This is achieved by the additional logic (U8, gates D and C) ahead of the S-R flip flop (formed from gates A and B of U2&3). The entire state machine is shown below:

<p width=100%, align="center">
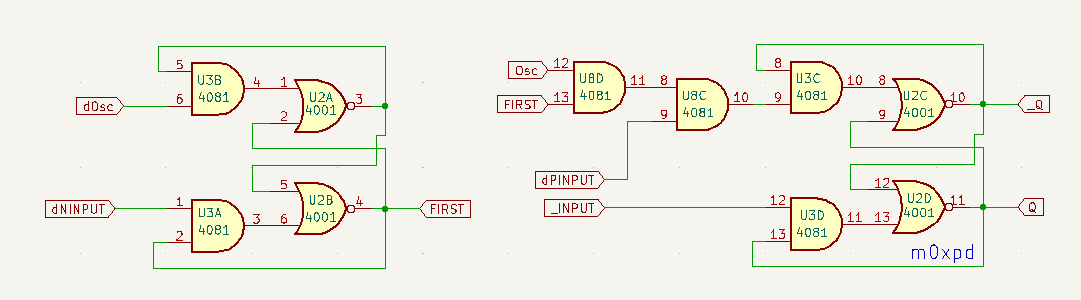
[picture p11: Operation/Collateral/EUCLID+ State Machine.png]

</p>

This amounts to what I describe as 'conditional modulation', for want of a better phrase. Rather than simply forming the logical AND of the clock and the internal oscillator (equivalent to multipliying the signals), derivation of the FIRST signal and its use in the formation of the SET input to the second S-R fip flop imposes a conditionality upon the modulation, which gives the interesting rhythmic patterns we seek. 

When x is not an integer, there are not a fixed number of periods of the 'Osc' signal in the repeat period (L times the clock period). This will make the resulting output change every period, which can give a useful result (particularly if x is close to an integer or is close to a ratio of small integers, like x ~ 3/2,  x ~ 7/5 etc). 

EUCLID+ is capable of hard-syncing the internal Oscillator to the output of its internal clock divider, which is provided for this purpose. 

## Performance Examples

The instance of the Euclidean Rhythm *E*(3,8) (= [x..x..x.]) reported on the [Front Page](https://github.com/m0xpd/EUCLIDplus/tree/main#) is actually rather rare. It was perfectly stable when the screenshot was captured, but it is difficult to reproduce. EUCLID+ more usually produces a pattern such as that seen below: 
<p width=100%, align="center">
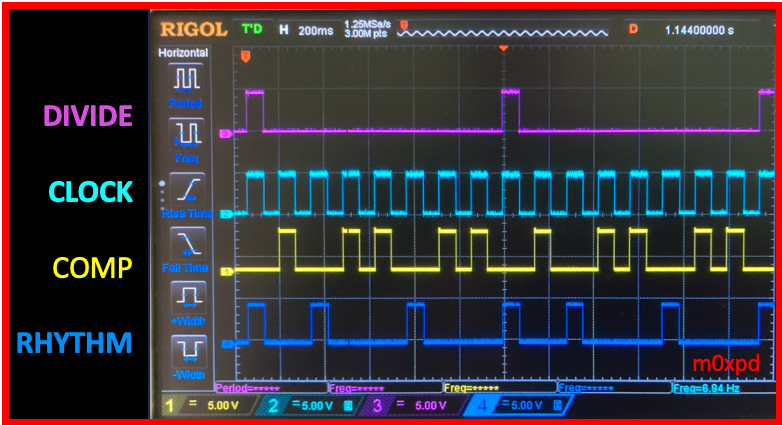
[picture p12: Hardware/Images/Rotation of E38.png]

</p>

It can be seen (with reference to the DIVIDE pulse, seen in the top Magenta trace) that the RHYTHM signal is  = [x.x..x..]. This sequence is *E*(3,8) rotated RIGHT by two 'places'. This rotation makes the signal in the image above an instance of the same "rhythm necklace" as *E*(3,8); it is the same rhythm, only displaced in start point / time reference. People familiar with Euclidean Rhythms from other sources (e.g. Tom Whiwell / Tombola's [code](https://www.modwiggler.com/forum/viewtopic.php?p=607737#p607737)), may have seen this rotation controllable via an "Offset" patameter.

The 'pure' (i.e. un-rotated) version of *E*(3,8) is - perhaps - unusual on EUCLID+ because it is only a conditionally stable behaviour, suggested by the 'glitch' seen in the COMP (yellow) output coincident with the DIVIDE pulse in the image on the Front Page. 

Following are some more 'scope traces of EUCLID+ performance in synchronous mode, producing Euclidean Rhythms (or - more correctly - rotations thereof).

The image below shows a rotation of *E*(3,7) (= [x.x.x..]).
<p width=100%, align="center">
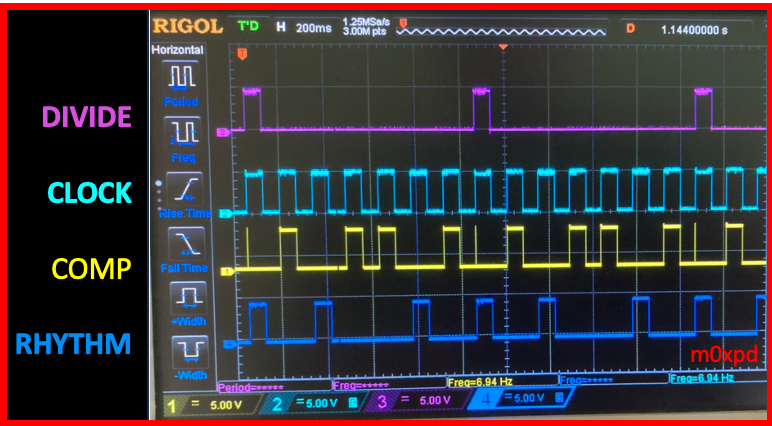
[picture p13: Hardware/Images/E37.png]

</p>

It is seen that (with reference to the DIVIDE output) RHYTHM = [x.x..x.]. It is seen that this signal is E(3,7) rotated LEFT by two 'places'. 

The image below shows EUCLID+ generating a rotation of *E*(5,12) (= [x..x.x..x.x.]).
<p width=100%, align="center">
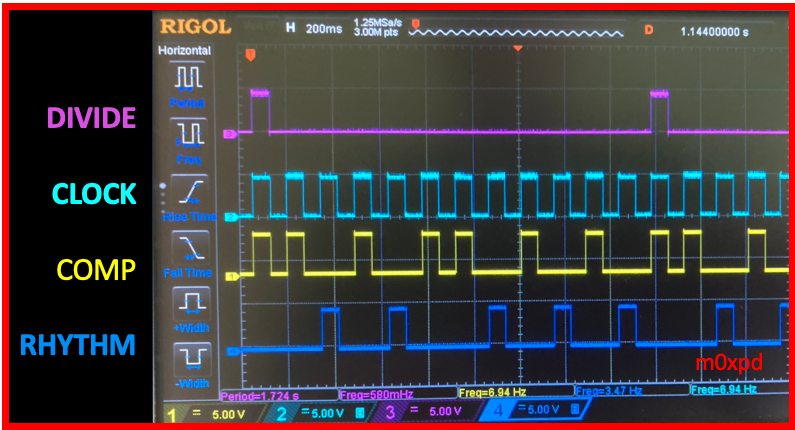
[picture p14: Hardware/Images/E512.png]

</p>
It is seen that (with reference to the DIVIDE output) RHYTHM = [..x.x..x.x.x]. It is seen that this signal is *E*(5,12) rotated LEFT by one 'place'. 

The image below shows EUCLID+ generating a rotation of  *E*(5,16) (= [x..x..x..x..x....]).
<p width=100%, align="center">
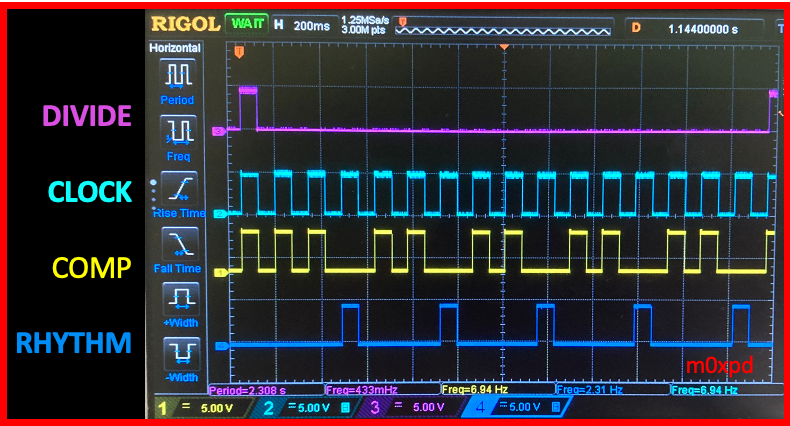
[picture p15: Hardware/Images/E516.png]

</p>
It is seen that (with reference to the DIVIDE output) RHYTHM = [...x..x..x..x..x]. It is seen that this signal is *E*(5,16) rotated LEFT by one 'place'.

## Synchronous Mode and Drift

When EUCLID+ is operated in synchronous mode, The hard-sync will force a periodic output, even when there is a non-integer number of periods of the internal oscillator in the clock divide length, x. The  non-integer values generate additional (non-Euclidean) patterns in synchronous mode, including some interesting "dotted" effects.

In practice, it is not possible to set the oscilator to an exact integer value of x, because of drift in EUCLID+'s oscillator and - indeed - because there may be drift in the incoming clock. For this reason, the synchronous mode is used in all cases where a fixed, periodic output sequence is sought and the asychronous mode is used when a free, evolving pattern is required. Even when the system is set to synchronous mode, the internal oscillator can still drift sufficiently to cause chqange in the output pattern, although this change should be negligible if the system is operating corectly. The system is never immune to changes in the incoming clock due to (e.g.) jitter. 

Variations arising from the inherent drift of EUCLID+'s simple VCO are seen as a positive feature of the system; those seeking more 'metronomic' and regular Euclidean Rhythm sources are encouraged to use one of the existing software-based solutions on the market. These variations give EUCLID+ a human / 'organic' feel, which I believe is associated to that which is sought by those who prefer 'analog' to 'digital' methods in synthesis (although, of course, EUCLID+ is mainly a switching/*digital* system).  A [software implementation of the EUCLID+ concept](https://github.com/m0xpd/EUCLIDplus/tree/main/Software%20Version#readme) avoids some of the issues inherent in the hardware approach.

Having disclosed the principle of operation, there now follows a description of the main circuit blocks in the electronics.

# Circuit Description

EUCLID+ is realised using 4000 series logic and op-amps, on two Printed Circuit boards, the schematics of which are described separately below.

## Main Board

The Main Board schematic is linked below (click on the graphic to open the file, which you can then download, or work with the KiCad .sch file in your PCB program).

<p width=100%, align="center">

</p>

Working around the schematic, reading left to right and down the page, we first meet:

## CLOCK PROCESSING
which accepts an externally applied clock signal from the [Control Board](https://github.com/m0xpd/EUCLIDplus/tree/main/Hardware/Control%20Board#readme). It is inverted by U1B, to produce the (positive-definite) signal _INPUT. It is also recitified to produce the (positive-definite) signal INPUT' and passed to an edge deterctor, to generate dPINPUT. The input signal also triggers a one-shot (U1A), the output of which is passed to another edge detector, which produces a signal dNINPUT, at the end of the one-shot's pulse.

The POWER, BOARD INTERFACE and POWER DISTRIBUTION blocks are trivial.

The **State Machine** has already been discusssed (above).

## INTERNAL OSCILLATOR
The VCO is a standard Shaner (a.k.a. "Synthmonger") 40106 oscillator, first published [here](https://electro-music.com/forum/topic-28799.html) back in 2008, which I have modified slightly to include the hard-sync (Q3, driven by enabling logic in U8 A&B). I have also d.c. coupled the oscillator to the subsequent comparator stages (U6 B&C) to avoid the long time constants implied by the low frequencies of operation, which would accompany the filtering in an a.c. coupled approach. U6B generates the high duty cycle Osc signal, whilst U6C makes an approximately square signal for the MULT output. An edge detector generates a pulse on the rising edge of the Osc signal ('dOsc'), which is buffered by spare gates in the 40106 to ensure it is at adequate level to drive logic.

The duty cycle of the internal oscillator signal 'Osc' is controlled by adjustment of the comparator threshold voltage set by RV1; this should be adjusted such that the (-12V) pulses on U6 pin 7 are of approximately 2ms duration. In the absence of an oscilloscope, adjust this trimmer until it puts -2.75V on pin 6 of U6 and make fine adjustment from there if required.  

## CLOCK DIVIDER A to D CONVERTER
The clock divider requires a parallel digital input. This would have been easiest to generate with a PIC or similar device reading the voltage on a potentiometer, but I wanted to make this a 'hardware-only' project. Accordingly, a ladder-type ADC is used, based on op-amp comparators. Precedents for this type of design exist in two-bit form [here](https://sfcs.neocities.org/module/SFP37/) and - more importantly - in a four-bit version [here](https://modwiggler.com/forum/viewtopic.php?p=464251#p464251). The structure is easy to extrapolate to five bits, but performance becomes sensitive to (e.g.) resistor tolerances at this resolution - I wouldn't fancy pushing the method beyond 5 bits! Still, it is working well-enough for this application.

## CLOCK DIVIDER
My original prototype used a simple 4017 decade counter, which was inadequate to achieve the 12 and 16 count sequences which are of particular interest among Euclidean Rhythms, forcing me to look to a different approach. 4017s are actually difficult to cascade in this type of application, so I turned instead to a 4024 7-stage counter, U11. I am using five of its stages to achieve the 5-bit count I require and detecting when I reach the end of the count using 4030 XOR gates, U9 & U10. The outputs of the XOR gates are ORed together by a 5 input OR gate formed by D14, D15, D16, D19 & D23 and Q5 and adjactent resistors. This OR gate resets the 4024 to 0 and sets the output flip-flops, U5 A&B,by clocking them, when the count reaches the number set on the A to D converter. Note that this has to be the desired output period (L) + 1; in other words to get an output with period 8, you set "9" (0, 1, 0, 0, 1) on the divider display LEDs.

Additionally, the system can be reset (e.g. to align the clock to an external reference beat on the clock, such as a "bar line") using the RESET signal.

## Control Board

The Control Board schematic is linked below (click on the graphic to open the file, which you can then download, or work with the KiCad .sch file in your PCB program).

<p width=100%, align="center">

</p>

The [Control Board](https://github.com/m0xpd/EUCLIDplus/tree/main/Hardware/Control%20Board#readme) hosts all User Interface controls, and all Inputs and Outputs. It also contains some signal conditioning circuitry to support the I/O functions.

Working L to R and top to bottom on the schematic:

## SYNC / FREE Control

Switching between synchronous and asynchronous mode is achieved by pressing the pushbutton SW1, which causes toggling action of the flip-flop formed by op-amp stage U1A.

An external input exceeding approximately 1.5V, applied to the Sync Input U$3, will drive the output of comparator stage U1B high.

The outputs of U1A and U1B are ORed togther by D1, D2 & R11. If either of these is high, the synchronous mode is enabled (ESYNC = 1) and D3 is illuminated.

## DIVIDE Control
The clock divider is set by a control voltage 'ADC_IN' which is the sum of a local voltage set on VR2 and the voltage input to the Divide input, U$1, applied to the attenuverter formed by U1C. C2 is critical to ensure sufficient noise rejection.

## CLOCK INPUT
A signal applied to the Clock input U$2 exceeding approx 1.5V will cause the output of comparator stage U2D ('CLOCK_IN') to go high.

## VCO Control
The internal oscillator frequency is set by the control voltage 'VCO_IN' formed of the sum of a local voltage set on VR4 and the voltage input to the Freq input, U$5, applied to the attenuverter formed by U2A. 

## DIVIDE LENGTH DISPLAY
The resistor network RN1 (in common with RN1 on the main board) is an 8-commoned package, of which only five resistors are used. I find these earier to source than other configurations. 
You should select the resistance to give appropriate brightness with YOUR LEDs - remember that the resistors and the LEDs are dropping 24V in this case. 10k worked for me, but your LEDs may not be the same as mine.

## OUTPUTS
The output stages are all similar, common collector types. Again, choose the current limiting resistors R41, R42, R43, R51 & R52 to suit your LEDs (this time dropping 11.5V).

The COMP output stage is slightly different than the rest, as it incorporates a diode AND gate (D14, D15) to combine the _Q signal with the system clock.

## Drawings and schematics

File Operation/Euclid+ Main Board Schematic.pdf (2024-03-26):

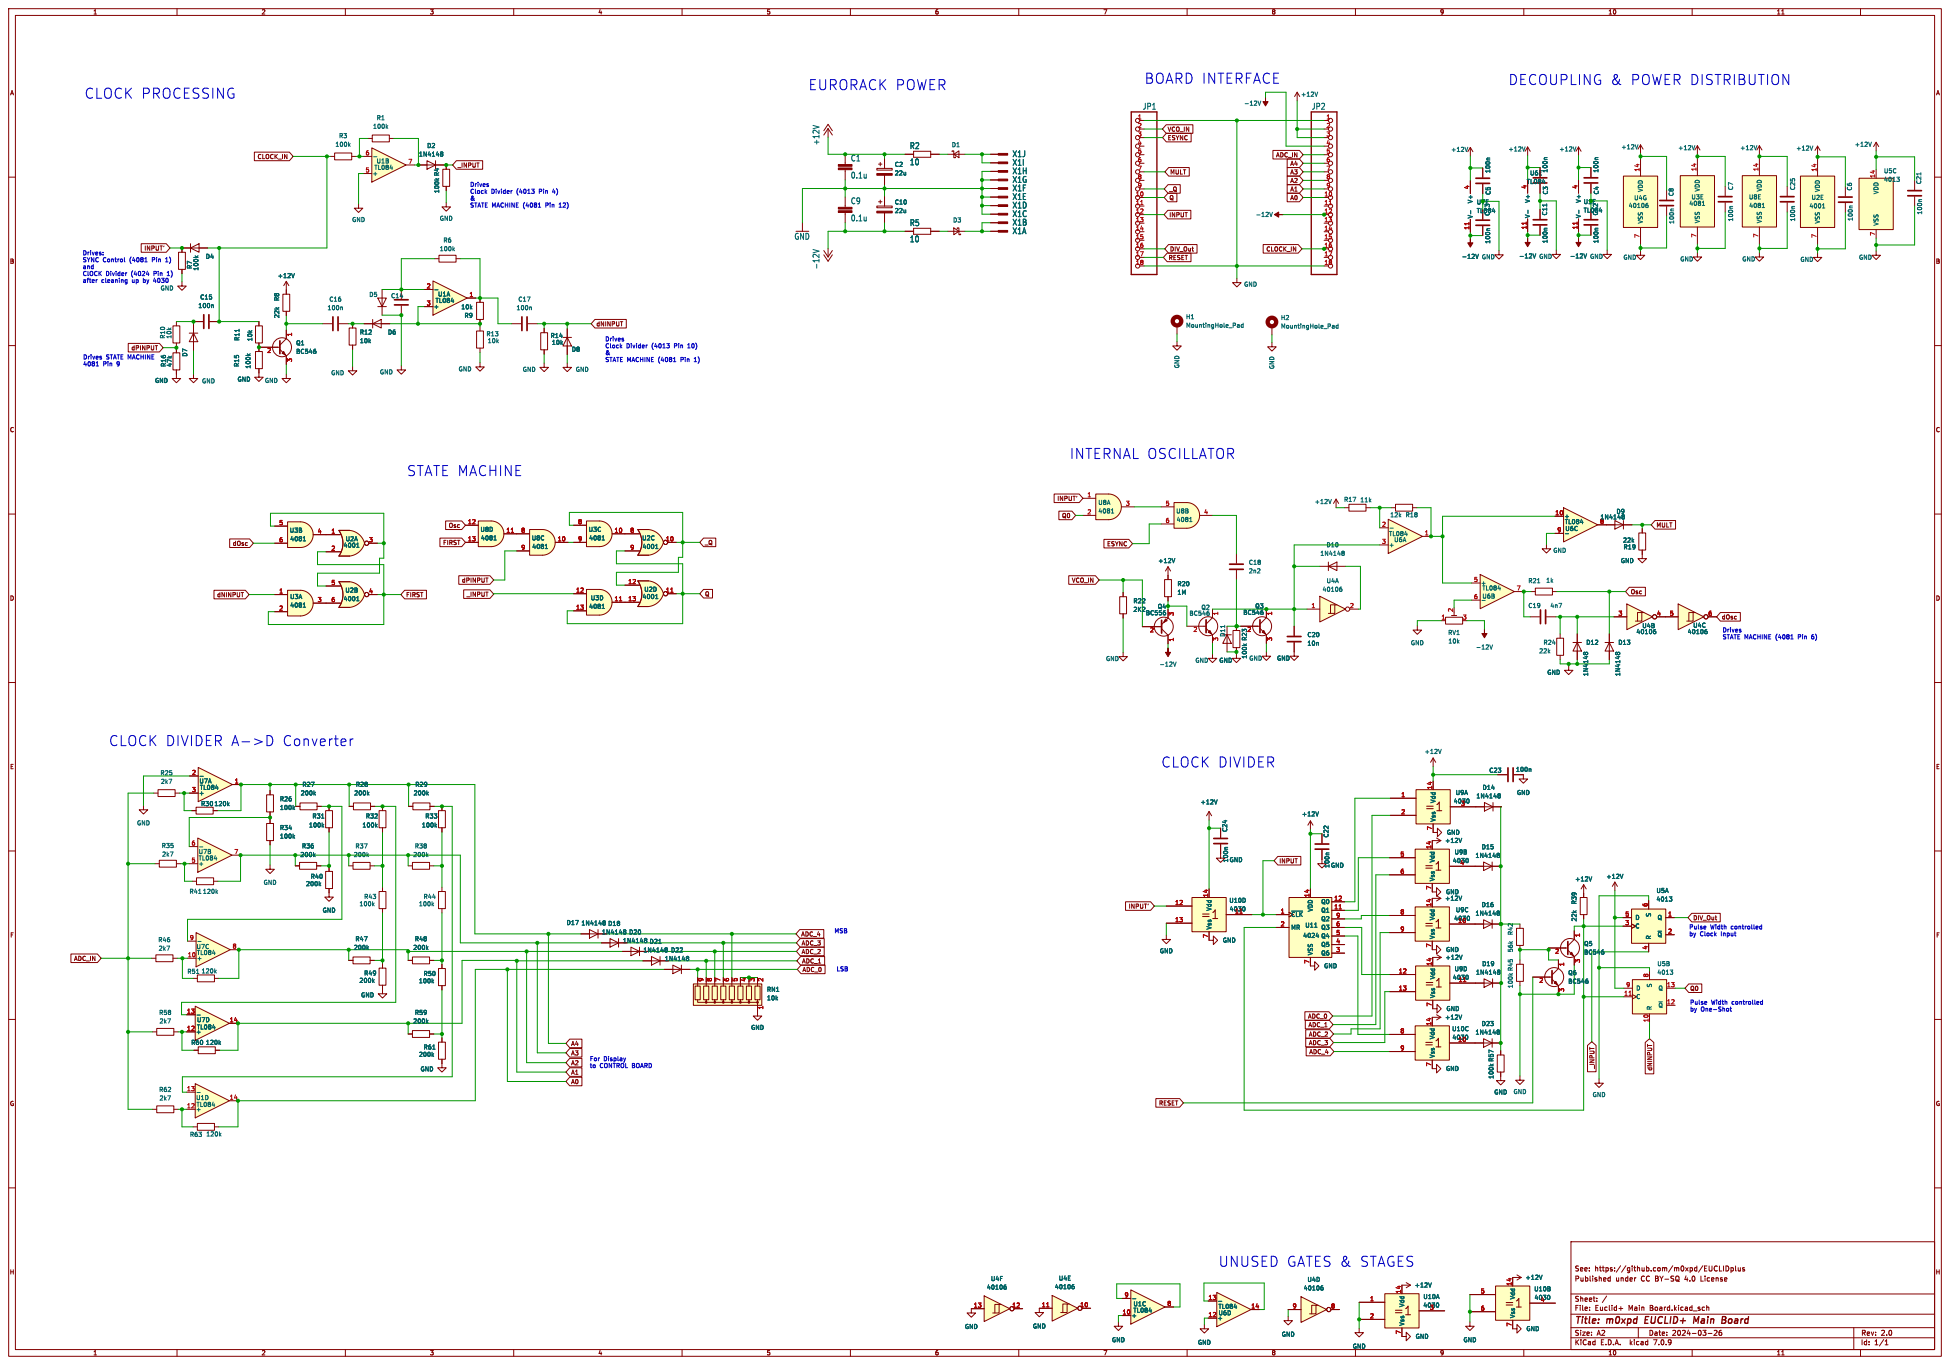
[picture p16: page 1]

Drives Clock Divider (4013 Pin 4) &

Drives Clock Divider (4013 Pin 10) &

Pulse Width controlled
by Clock Input Pulse Width controlled

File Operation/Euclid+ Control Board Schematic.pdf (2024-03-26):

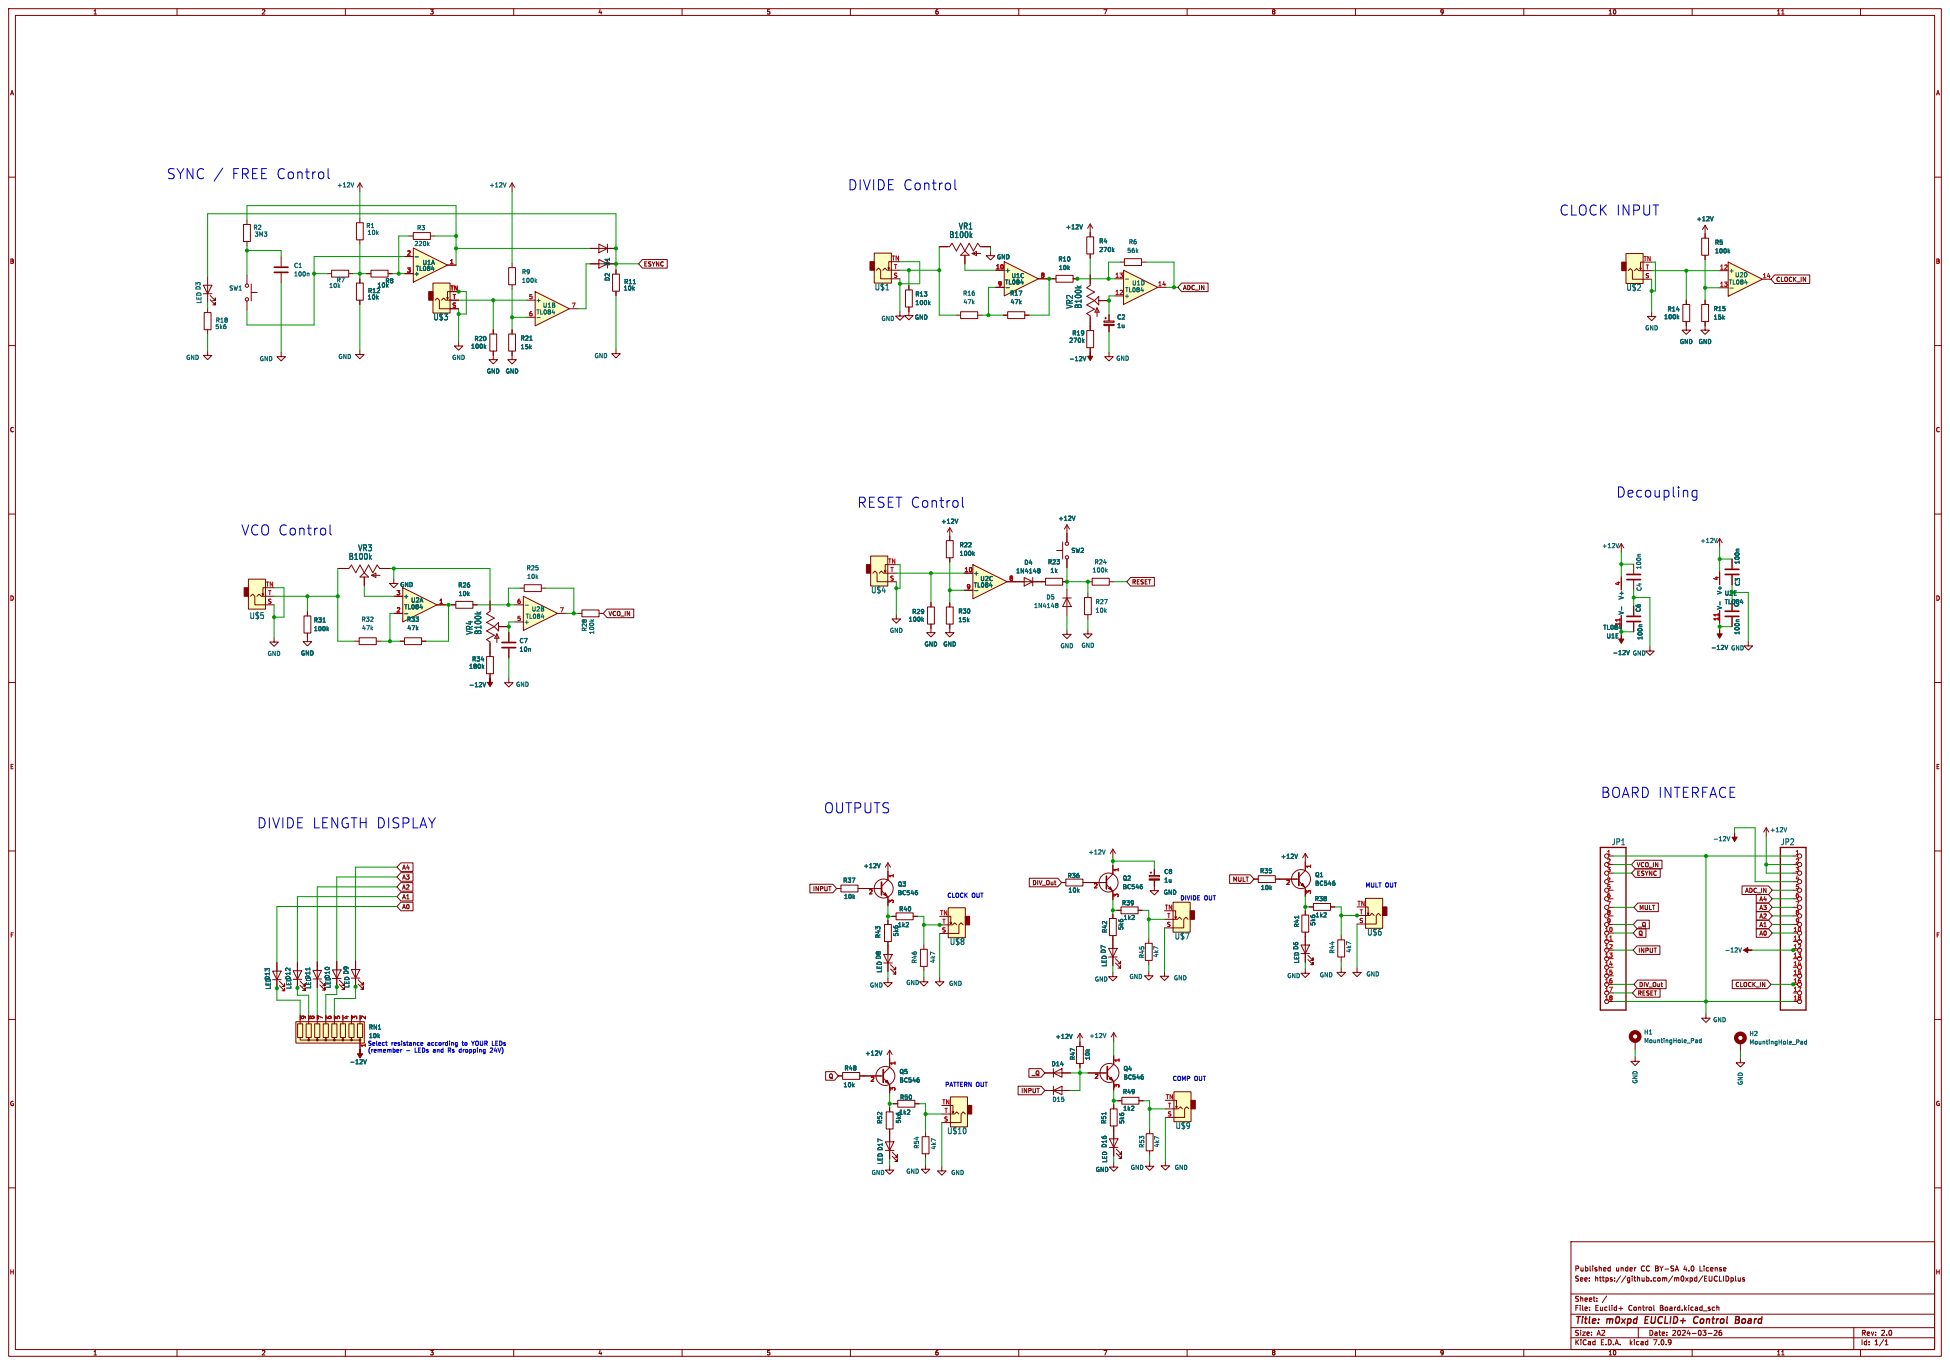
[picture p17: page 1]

MULT OUT DIVIDE Control

COMP OUT DIVIDE LENGTH DISPLAY

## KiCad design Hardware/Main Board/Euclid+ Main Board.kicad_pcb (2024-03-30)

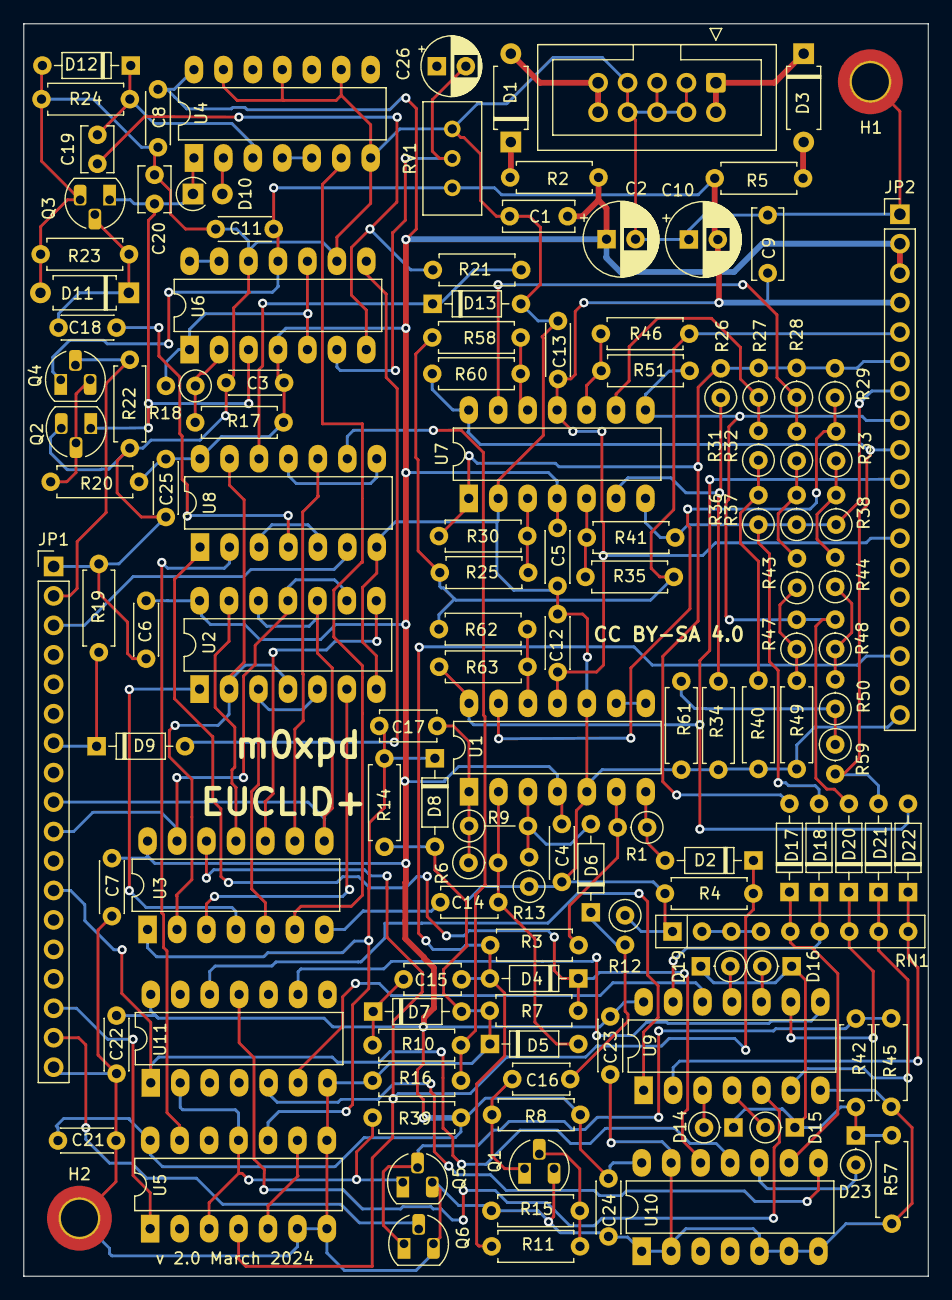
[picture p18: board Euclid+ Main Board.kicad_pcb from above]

Board: 2 copper layers, 78.0 x 108.0 mm, 131 parts (0 on the bottom side), 95 nets.

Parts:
C1, C9: 0.1u; C_Disc_D6.0mm_W2.5mm_P5.00mm
C2, C10: 22u; CP_Radial_D6.3mm_P2.50mm
C3, C4, C5, C6, C7, C8, C11, C12, C13, C21, C22, C23, C24, C25: 100n; C_Disc_D4.3mm_W1.9mm_P5.00mm
C14, C15, C16, C17: 100n; C_Disc_D4.7mm_W2.5mm_P5.00mm
C18: 2n2; C_Disc_D4.3mm_W1.9mm_P5.00mm
C19: 4n7; C_Disc_D3.8mm_W2.6mm_P2.50mm
C20: 10n; C_Disc_D3.8mm_W2.6mm_P2.50mm
C26: 1u; CP_Radial_D5.0mm_P2.50mm
D1, D3: D_Schottky_Small; D_A-405_P7.62mm_Horizontal
D2, D4, D5, D6, D7, D8, D9, D12, D13, D17, D18, D20, D21, D22: 1N4148; D_DO-35_SOD27_P7.62mm_Horizontal
D10: 1N4148; D_A-405_P2.54mm_Vertical_AnodeUp
D11: 1N4148; D_A-405_P7.62mm_Horizontal
D14, D15, D16, D19, D23: 1N4148; D_DO-35_SOD27_P2.54mm_Vertical_KathodeUp
H1, H2: MountingHole_Pad; MountingHole_3.2mm_M3_DIN965_Pad_TopBottom
JP1, JP2: PinHeader_1x18_P2.54mm_Vertical
Q1, Q2, Q3, Q5, Q6: BC546; TO-92_HandSolder
Q4: BC556; TO-92_HandSolder
R1, R6, R26, R31, R32, R33, R43, R44, R50: 100k; R_Axial_DIN0207_L6.3mm_D2.5mm_P2.54mm_Vertical
R2, R5: 10; R_Axial_DIN0207_L6.3mm_D2.5mm_P7.62mm_Horizontal
R3, R4, R7, R15, R23, R34, R45, R57: 100k; R_Axial_DIN0207_L6.3mm_D2.5mm_P7.62mm_Horizontal
R8, R19, R24, R39: 22k; R_Axial_DIN0207_L6.3mm_D2.5mm_P7.62mm_Horizontal
R9: 10k; R_Axial_DIN0207_L6.3mm_D2.5mm_P5.08mm_Vertical
R10, R11, R14: 10k; R_Axial_DIN0207_L6.3mm_D2.5mm_P7.62mm_Horizontal
R12, R13: 10k; R_Axial_DIN0207_L6.3mm_D2.5mm_P2.54mm_Vertical
R16: 47k; R_Axial_DIN0207_L6.3mm_D2.5mm_P7.62mm_Horizontal
R17: 11k; R_Axial_DIN0207_L6.3mm_D2.5mm_P7.62mm_Horizontal
R18: 12k; R_Axial_DIN0207_L6.3mm_D2.5mm_P2.54mm_Vertical
R20: 1M; R_Axial_DIN0207_L6.3mm_D2.5mm_P7.62mm_Horizontal
R21: 1k; R_Axial_DIN0207_L6.3mm_D2.5mm_P7.62mm_Horizontal
R22: 2K2; R_Axial_DIN0207_L6.3mm_D2.5mm_P7.62mm_Horizontal
R25, R35, R46, R58, R62: 2k7; R_Axial_DIN0207_L6.3mm_D2.5mm_P7.62mm_Horizontal
R27, R28, R29, R36, R37, R38, R47, R48, R59: 200k; R_Axial_DIN0207_L6.3mm_D2.5mm_P2.54mm_Vertical
R30, R41, R51, R60, R63: 120k; R_Axial_DIN0207_L6.3mm_D2.5mm_P7.62mm_Horizontal
R40, R49, R61: 200k; R_Axial_DIN0207_L6.3mm_D2.5mm_P7.62mm_Horizontal
R42: 56k; R_Axial_DIN0207_L6.3mm_D2.5mm_P7.62mm_Horizontal
RN1: 10k; R_Array_SIP9
RV1: 10k; Potentiometer_Bourns_3296W_Vertical
U1, U6, U7: TL084; DIP-14_W7.62mm_LongPads
U2: 4001; DIP-14_W7.62mm_LongPads
U3, U8: 4081; DIP-14_W7.62mm_LongPads
U4: 40106; DIP-14_W7.62mm_LongPads
U5: 4013; DIP-14_W7.62mm_LongPads
U9, U10: 4030; DIP-14_W7.62mm_LongPads
U11: 4024; DIP-14_W7.62mm_LongPads
X1: 2510-; IDC-Header_2x05_P2.54mm_Vertical

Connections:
+12V: C1.1, C2.1, C3.1, C4.1, C5.1, C6.1, C7.1, C8.1, C21.1, C22.1, C23.1, C24.1, C25.1, JP2.2, JP2.3, R2.1, R8.2, R17.2, R20.1, R39.2, U1.4 (V+), U2.14 (VDD), U3.14 (VDD), U4.14 (VDD), U5.5 (D), U5.9 (D), U5.14 (VDD), U6.4 (V+), U7.4 (V+), U8.14 (VDD), U9.14 (Vdd), U10.14 (Vdd), U11.14 (VDD)
-12V: C9.2, C10.2, C11.2, C12.2, C13.2, JP2.4, JP2.12, Q4.1 (C), R5.1, RV1.3, U1.11 (V-), U6.11 (V-), U7.11 (V-)
A0: D22.2 (A), JP2.10, R63.2, U1.14
A1: D21.2 (A), JP2.9, R59.2, R60.2, U7.14
A2: D20.2 (A), JP2.8, R47.2, R48.2, R51.2, U7.8
A3: D18.2 (A), JP2.7, R36.1, R37.1, R38.1, R41.2, U7.7
A4: D17.2 (A), JP2.6, R26.2, R27.2, R28.2, R29.2, R30.2, U7.1
ADC_0: D22.1 (K), RN1.9 (R8), U9.2
ADC_1: D21.1 (K), RN1.8 (R7), U9.6
ADC_2: D20.1 (K), RN1.7 (R6), U9.9
ADC_3: D18.1 (K), RN1.6 (R5), U9.13
ADC_4: D17.1 (K), RN1.5 (R4), U10.9
ADC_IN: JP2.5, R25.1, R35.1, R46.1, R58.1, R62.1
CLOCK_IN: C15.2, D4.2 (A), JP2.16, R3.2, R11.2
DIV_Out: JP1.16, U5.1 (Q)
ESYNC: JP1.3, U8.6
FIRST: U2.2, U2.4, U3.2, U8.13
GND: C1.2, C2.2, C3.2, C4.2, C5.2, C6.2, C7.2, C8.2, C9.1, C10.1, C11.1, C12.1, C13.1, C14.1, C20.2, C21.2, C22.2, C23.2, C24.2, C25.2, C26.1, D5.1 (K), D7.2 (A), D8.2 (A), D11.2 (A), D12.2 (A), D13.2 (A), H1.1, H2.1, JP1.1, JP1.18, JP2.1, JP2.18, Q1.3 (E), Q2.3 (E), Q3.3 (E), Q5.3 (E), Q6.3 (E), R4.1, R7.1, R12.1, R13.1, R14.1, R15.1, R16.1, R19.2, R22.1, R23.1, R24.1, R34.1, R40.1, R45.1, R49.1, R57.1, R61.1, RN1.1 (common), RV1.1, U1.5 (+), U1.10 (+), U2.7 (VSS), U3.7 (VSS), U4.7 (VSS), U4.9, U4.11, U4.13, U5.6 (S), U5.7 (VSS), U5.8 (S), U6.9 (-), U6.12 (+), U7.2 (-), U8.7 (VSS), U9.7 (Vss), U10.1, U10.2, U10.5, U10.6, U10.7 (Vss), U10.13, U11.7 (VSS), X1.3 (KL), X1.4 (KL), X1.5 (KL), X1.6 (KL), X1.7 (KL), X1.8 (KL)
INPUT: JP1.12, U10.11, U11.1 (~CLK)
INPUT': D4.1 (K), R7.2, U8.1, U10.12
MULT: D9.1 (K), JP1.7, R19.1
unnamed: C17.1, R6.1, R9.1, U1.1
unnamed: C18.2, U8.4
unnamed: C19.1, R21.2, U6.7
unnamed: D1.2 (A), X1.9 (KL), X1.10 (KL)
unnamed: D1.1 (K), R2.2
unnamed: D2.2 (A), R1.1, U1.7
unnamed: D3.2 (A), R5.2
unnamed: D3.1 (K), X1.1 (KL), X1.2 (KL)
unnamed: C14.2, D5.2 (A), R6.2, U1.2 (-)
unnamed: D6.2 (A), R9.2, R13.2, U1.3 (+)
unnamed: C16.2, D6.1 (K), R12.2
unnamed: C15.1, D7.1 (K), R10.2
unnamed: D9.2 (A), U6.8
unnamed: D10.2 (A), U4.2
unnamed: C20.1, D10.1 (K), Q2.1 (C), Q3.1 (C), U4.1, U6.3 (+)
unnamed: C18.1, D11.1 (K), Q3.2 (B), R23.2
unnamed: C19.2, D12.1 (K), R24.2, U4.3
unnamed: D14.2 (A), U9.3
unnamed: D14.1 (K), D15.1 (K), D16.1 (K), D19.1 (K), D23.1 (K), R42.2, R57.2
unnamed: D15.2 (A), U9.4
unnamed: D16.2 (A), U9.10
unnamed: D19.2 (A), U9.11
unnamed: D23.2 (A), U10.10
unnamed: Q1.2 (B), R11.1, R15.2
unnamed: C16.1, Q1.1 (C), R8.1
unnamed: Q2.2 (B), Q4.3 (E), R20.2
unnamed: Q5.2 (B), Q6.1 (C), R42.1, R45.2
unnamed: Q5.1 (C), R39.1, U5.3 (C), U5.11 (C), U11.2 (MR)
unnamed: R31.1, R36.2, R40.2
unnamed: R32.1, R37.2, R43.2
unnamed: R33.1, R38.2, R44.2
unnamed: R43.1, R47.1, R49.2
unnamed: R44.1, R48.1, R50.2
unnamed: R50.1, R59.1, R61.2
unnamed: RN1.2 (R1), RN1.3 (R2), RN1.4 (R3)
unnamed: R1.2, R3.1, U1.6 (-)
unnamed: U1.8, U1.9 (-)
unnamed: R62.2, R63.1, U1.12 (+)
unnamed: R29.1, R33.2, U1.13 (-)
unnamed: U2.1, U3.4
unnamed: U2.3, U2.5, U3.5
unnamed: U2.6, U3.3
unnamed: U2.8, U3.10
unnamed: U2.13, U3.11
unnamed: U3.9, U8.10
unnamed: U4.4, U4.5
unnamed: R17.1, R18.1, U6.2 (-)
unnamed: R18.2, U6.1, U6.5 (+), U6.10 (+)
unnamed: C26.2, RV1.2, U6.6 (-)
unnamed: U6.13 (-), U6.14
unnamed: R25.2, R30.1, U7.3 (+)
unnamed: R35.2, R41.1, U7.5 (+)
unnamed: R26.1, R34.2, U7.6 (-)
unnamed: R46.2, R51.1, U7.10 (+)
unnamed: R27.1, R31.2, U7.9 (-)
unnamed: R58.2, R60.1, U7.12 (+)
unnamed: R28.1, R32.2, U7.13 (-)
unnamed: U8.3, U8.5
unnamed: U8.8, U8.11
unnamed: U9.1, U11.12 (Q0)
unnamed: U9.5, U11.11 (Q1)
unnamed: U9.8, U11.9 (Q2)
unnamed: U9.12, U11.6 (Q3)
unnamed: U10.8, U11.5 (Q4)
Osc: D13.1 (K), R21.1, U8.12
Q: JP1.10, U2.9, U2.11, U3.13
Q0: U5.13 (Q), U8.2
RESET: JP1.17, Q6.2 (B)
VCO_IN: JP1.2, Q4.2 (B), R22.2
_INPUT: D2.1 (K), R4.2, U3.12, U5.4 (R)
_Q: JP1.9, U2.10, U2.12, U3.8
dNINPUT: C17.2, D8.1 (K), R14.2, U3.1, U5.10 (R)
dOsc: U3.6, U4.6
dPINPUT: R10.1, R16.2, U8.9

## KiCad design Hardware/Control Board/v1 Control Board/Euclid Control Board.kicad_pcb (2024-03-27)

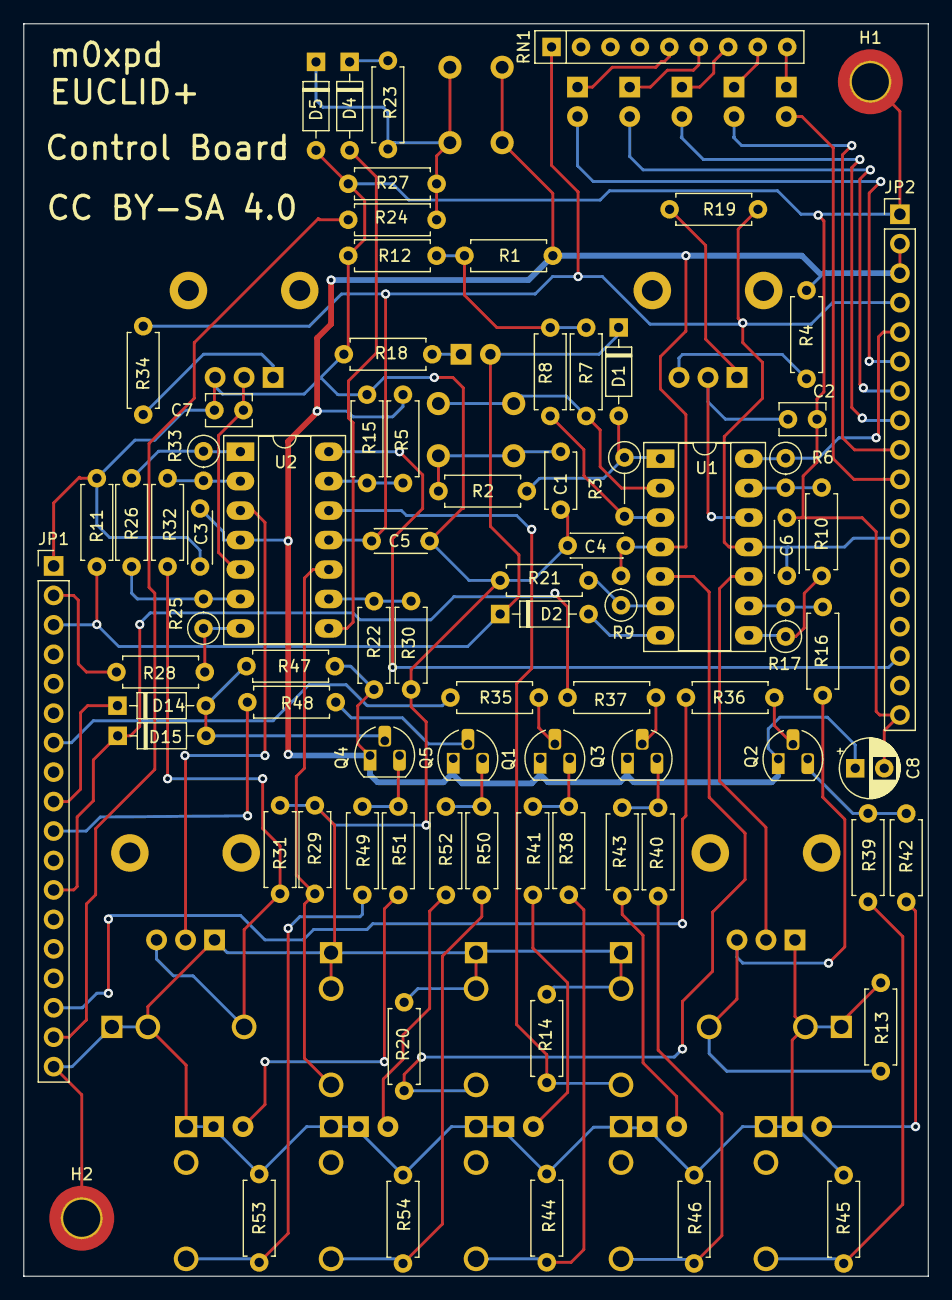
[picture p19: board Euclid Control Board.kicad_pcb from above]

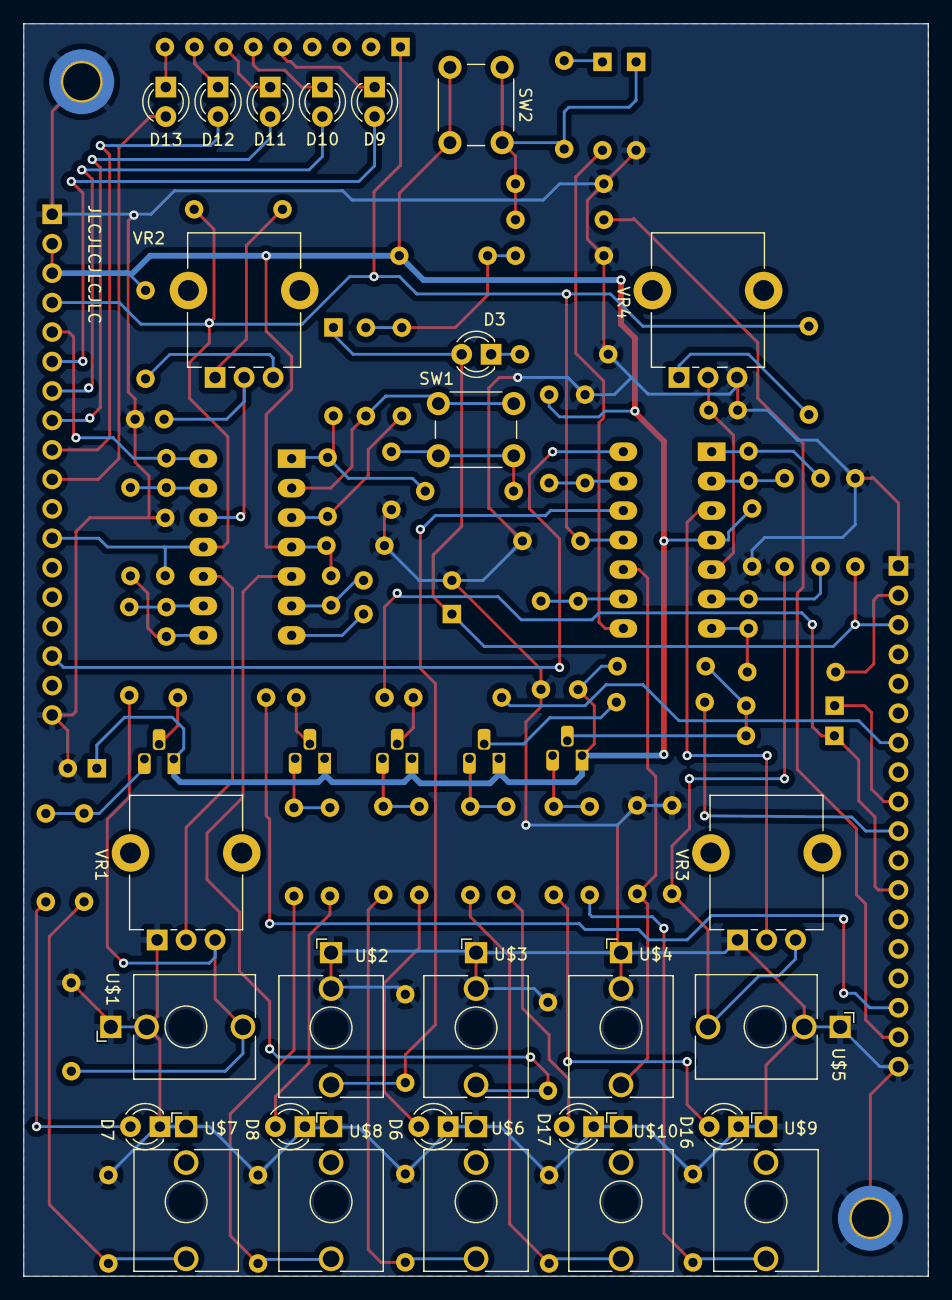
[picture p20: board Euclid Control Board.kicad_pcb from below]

Board: 2 copper layers, 78.0 x 108.0 mm, 107 parts (27 on the bottom side), 75 nets.

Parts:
C1: 100n; C_Disc_D4.7mm_W2.5mm_P5.00mm
C2, C7: 10n; C_Disc_D3.8mm_W2.6mm_P2.50mm
C3, C4, C5, C6: 100n; C_Disc_D4.3mm_W1.9mm_P5.00mm
C8: 1u; CP_Radial_D5.0mm_P2.50mm
D1, D2, D4, D5, D14, D15: 1N4148; D_DO-35_SOD27_P7.62mm_Horizontal
D3, D6, D7, D8, D9, D10, D11, D12, D13, D16, D17: LED; LED_D3.0mm
H1, H2: MountingHole_Pad; MountingHole_3.2mm_M3_DIN965_Pad_TopBottom
JP1, JP2: PinHeader_1x18_P2.54mm_Vertical
Q1, Q2, Q3, Q4, Q5: BC546; TO-92_HandSolder
R1, R7, R8, R10, R11, R12, R26, R27, R35, R36, R37, R47, R48, R49, R51: 10k; R_Axial_DIN0207_L6.3mm_D2.5mm_P7.62mm_Horizontal
R2: 3M3; R_Axial_DIN0207_L6.3mm_D2.5mm_P7.62mm_Horizontal
R3: 220k; R_Axial_DIN0207_L6.3mm_D2.5mm_P5.08mm_Vertical
R4, R19: 270k; R_Axial_DIN0207_L6.3mm_D2.5mm_P7.62mm_Horizontal
R5, R13, R14, R20, R22, R24, R28, R29, R31: 100k; R_Axial_DIN0207_L6.3mm_D2.5mm_P7.62mm_Horizontal
R6: 56k; R_Axial_DIN0207_L6.3mm_D2.5mm_P2.54mm_Vertical
R9: 100k; R_Axial_DIN0207_L6.3mm_D2.5mm_P2.54mm_Vertical
R15, R21, R30: 15k; R_Axial_DIN0207_L6.3mm_D2.5mm_P7.62mm_Horizontal
R16, R32: 47k; R_Axial_DIN0207_L6.3mm_D2.5mm_P7.62mm_Horizontal
R17, R33: 47k; R_Axial_DIN0207_L6.3mm_D2.5mm_P2.54mm_Vertical
R18, R23, R41, R42, R43, R52: 1k; R_Axial_DIN0207_L6.3mm_D2.5mm_P7.62mm_Horizontal
R25: 10k; R_Axial_DIN0207_L6.3mm_D2.5mm_P2.54mm_Vertical
R34: 180k; R_Axial_DIN0207_L6.3mm_D2.5mm_P7.62mm_Horizontal
R38, R39, R40, R50: 1k2; R_Axial_DIN0207_L6.3mm_D2.5mm_P7.62mm_Horizontal
R44, R45, R46, R53, R54: 4k7; R_Axial_DIN0207_L6.3mm_D2.5mm_P7.62mm_Horizontal
RN1: 100k; R_Array_SIP9
SW1, SW2: SW_Push; SW_PUSH_6mm_H13mm
U1, U2: TL084; DIP-14_W7.62mm_Socket_LongPads
U$1, U$2, U$3, U$4, U$5, U$6, U$7, U$8, U$9, U$10: THONKICONN_JACK; Jack_3.5mm_QingPu_WQP-PJ398SM_Vertical_CircularHoles
VR1, VR2, VR3, VR4: B100k; Potentiometer_Alpha_RD901F-40-00D_Single_Vertical_CircularH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

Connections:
+12V: C3.1, C4.1, C8.1, JP2.2, JP2.3, Q1.1 (C), Q2.1 (C), Q3.1 (C), Q4.1 (C), Q5.1 (C), R1.2, R4.1, R5.2, R9.2, R22.2, R47.2, SW2.2, U1.4 (V+), U2.4 (V+)
-12V: C5.2, C6.2, JP2.4, JP2.12, R19.2, R34.2, RN1.1 (common), U1.11 (V-), U2.11 (V-)
A0: D13.2 (A), JP2.10
A1: D12.2 (A), JP2.9
A2: D11.2 (A), JP2.8
A3: D10.2 (A), JP2.7
A4: D9.2 (A), JP2.6
ADC_IN: JP2.5, R6.1, U1.14
CLOCK_IN: JP2.16, U2.14
DIV_Out: JP1.16, R36.2
ESYNC: D1.1 (K), D2.1 (K), D3.2 (A), JP1.3, R11.2
GND: C1.1, C2.1, C3.2, C4.2, C5.1, C6.1, C7.1, C8.2, D5.2 (A), D6.1 (K), D7.1 (K), D8.1 (K), D16.1 (K), D17.1 (K), H1.1, H2.1, JP1.1, JP1.18, JP2.1, JP2.18, R11.1, R12.1, R13.2, R14.1, R15.1, R18.1, R20.1, R21.1, R27.1, R29.1, R30.1, R31.2, R44.1, R45.1, R46.1, R53.1, R54.1, U$1.S, U$1.TN, U$2.S, U$2.TN, U$3.S, U$3.TN, U$4.S, U$4.TN, U$5.S, U$5.TN, U$6.S, U$7.S, U$8.S, U$9.S, U$10.S, VR1.1 (A), VR3.1 (A), VR4.3 (E)
INPUT: D15.1 (K), JP1.12, R37.2
MULT: JP1.7, R35.2
unnamed: C1.2, R2.1, SW1.2
unnamed: D1.2 (A), R2.2, R3.1, U1.1
unnamed: D2.2 (A), U1.7
unnamed: D3.1 (K), R18.2
unnamed: D4.2 (A), U2.8
unnamed: D4.1 (K), R23.2
unnamed: D5.1 (K), R23.1, R24.2, R27.2, SW2.1
unnamed: D6.2 (A), R41.1
unnamed: D7.2 (A), R42.1
unnamed: D8.2 (A), R43.1
unnamed: D9.1 (K), RN1.5 (R4)
unnamed: D10.1 (K), RN1.6 (R5)
unnamed: D11.1 (K), RN1.7 (R6)
unnamed: D12.1 (K), RN1.8 (R7)
unnamed: D13.1 (K), RN1.9 (R8)
unnamed: D14.2 (A), D15.2 (A), Q4.2 (B), R47.1
unnamed: D16.2 (A), R51.1
unnamed: D17.2 (A), R52.1
unnamed: Q1.2 (B), R35.1
unnamed: Q1.3 (E), R38.2, R41.2
unnamed: Q2.2 (B), R36.1
unnamed: Q2.3 (E), R39.2, R42.2
unnamed: Q3.2 (B), R37.1
unnamed: Q3.3 (E), R40.2, R43.2
unnamed: Q4.3 (E), R49.2, R51.2
unnamed: Q5.2 (B), R48.1
unnamed: Q5.3 (E), R50.2, R52.2
unnamed: R1.1, R7.1, R8.2, R12.2
unnamed: R10.2, R17.1, U1.8
unnamed: R25.1, R28.1, U2.7
unnamed: R26.2, R33.1, U2.1
unnamed: R38.1, R44.2, U$6.T
unnamed: R39.1, R45.2, U$7.T
unnamed: R40.1, R46.2, U$8.T
unnamed: R49.1, R53.2, U$9.T
unnamed: R50.1, R54.2, U$10.T
unnamed: R3.2, R8.1, U1.3 (+)
unnamed: R7.2, SW1.1, U1.2 (-)
unnamed: R20.2, U1.5 (+), U$3.T
unnamed: R9.1, R21.2, U1.6 (-)
unnamed: U1.10 (+), VR1.2 (S)
unnamed: R16.1, R17.2, U1.9 (-)
unnamed: C2.2, U1.12 (+), VR2.2 (S)
unnamed: R6.2, R10.1, U1.13 (-)
unnamed: U2.3 (+), VR3.2 (S)
unnamed: R32.1, R33.2, U2.2 (-)
unnamed: C7.2, U2.5 (+), VR4.2 (S)
unnamed: R25.2, R26.1, U2.6 (-)
unnamed: R29.2, U2.10 (+), U$4.T
unnamed: R22.1, R30.2, U2.9 (-)
unnamed: R14.2, U2.12 (+), U$2.T
unnamed: R5.1, R15.2, U2.13 (-)
unnamed: R13.1, R16.2, U$1.T, VR1.3 (E)
unnamed: R19.1, VR2.1 (A)
unnamed: R4.2, VR2.3 (E)
unnamed: R31.1, R32.2, U$5.T, VR3.3 (E)
unnamed: R34.1, VR4.1 (A)
Q: JP1.10, R48.2
RESET: JP1.17, R24.1
VCO_IN: JP1.2, R28.2
_Q: D14.1 (K), JP1.9

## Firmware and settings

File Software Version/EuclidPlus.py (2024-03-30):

# EuclidPlus.py
# 
# v0.1
# for the RPi PICO
#
# P Darlington m0xpd
# See https://github.com/m0xpd/EUCLIDplus

from machine import ADC, Pin
from machine import Timer

import time
import math
import array as arr
interrupt_flag=0
sync_interrupt_flag = 0
debounce_time=0
clk_in = Pin(5, Pin.IN, Pin.PULL_UP)	# Clock input
clk_in2 = Pin(6, Pin.IN, Pin.PULL_UP)	# Repeat of the clock to set up a second HW Interrupt!
syncpin = Pin(7, Pin.IN, Pin.PULL_UP)	# Sync Toggle Pushbutton
led = Pin(12, Pin.OUT)					
led2 = Pin(13, Pin.OUT)					
out_clock = Pin(14, Pin.OUT)			
comp = Pin(10, Pin.OUT)					# comp is the COMPLEMENT of the pattern output
div = Pin(11, Pin.OUT)					# div is the DIVIDE output
pattern = Pin(15, Pin.OUT)				# pettern is the main output
syncLED = Pin(16, Pin.OUT)				# sync/free status
FIRSTPin = Pin(17, Pin.OUT)
pot = ADC(26)							# Read Clock Divide Value
pot2 = ADC(27)							# Read Internal Oscillator Frequency
# Declare and inmitialise global variables...
count=0
last_beat=0
beat=0
BPM=10
beta=0.25
Old_Tavg=0
clock_multiply=4
tperiod = 130
tperiod2 = 10
old_tperiod = 10
out_count = 1
Euclid=1
max_count = 4
sync=1
osc = 0
FIRST=0
Q = 0
INPUT = 0
oldINPUT = 0		# Previous values of INPUT in a delay line
old1INPUT = 0
old2INPUT = 0
old3INPUT = 0
        

# A few function definitions....

def synccallback(syncpin):
    # Handle the togging pushbutton to set sync/free operation
    global sync_interrupt_flag, debounce_time
    if (time.ticks_ms()-debounce_time) > 250:
        sync_interrupt_flag= 1
        debounce_time=time.ticks_ms()

def Q_Off(Source):
    # Turn output Off (part of the main State Machine)
    global Q
    Q = 0
    pattern.value(Q)


def callback(clk_in):
    # Handle Leading edge of clock actions...
    global interrupt_flag, debounce_time, beat, last_beat, BPM, beta, Old_Tavg, FIRST, osc, Q
    interrupt_flag= 1
    #Manage STATE MACHINE....
    if((FIRST==1)and(osc==1)):
        Q = 1
        pattern.value(Q)        
    led.value(1)
    led_Timer = Timer(period=5, mode=Timer.ONE_SHOT, callback=LED_Off)
      
      
    if(Q == 0):
        comp.value(1)

def callback2(clk_in2):
    # Handle actions on falling edge of clock
    global Q
    Q = 0
    pattern.value(Q)
    comp.value(0)
    div.value(0)

   
def LED_Off(Source):
    # Set led = 0
    global FIRST, Q    
    FIRST = 0
    FIRSTPin.value(FIRST) 
    led.value(0)


def LED2_Off(Source):
    # set led2 = 0
    led2.value(0)


def Out_Off_Handler(Source):
    # Operate Internal Oscillator (Low Phase) 
    global osc
    osc = 0    
    out_clock.value(osc)
    out_off.init(period=1, mode=Timer.ONE_SHOT, callback=Out_On_Handler)
    


def Out_On_Handler(Source):
    # Operate Internal Oscillator (High Phase)
    global tperiod, FIRST, osc
    osc = 1    
    out_clock.value(osc)
    FIRST = 1
    FIRSTPin.value(FIRST)
    out_on.init(period=tperiod, mode=Timer.ONE_SHOT, callback=Out_Off_Handler)
    
# End of function definitions
#================================================================================
# Now some Timers and Interrupt Requests...


out_on=Timer(period=tperiod, mode=Timer.ONE_SHOT, callback=Out_Off_Handler)
out_off=Timer(period=1, mode=Timer.ONE_SHOT, callback=Out_On_Handler)
syncpin.irq(trigger=Pin.IRQ_RISING, handler=synccallback)
clk_in.irq(trigger=Pin.IRQ_FALLING, handler=callback)
clk_in2.irq(trigger=Pin.IRQ_RISING, handler=callback2)


# This is the main 'Loop'....


while True:
    if interrupt_flag is 1:
          raw = pot.read_u16()                                             # get the clock divide value
          max_count=math.floor(raw * 31 / 65535 ) + 1												
          raw_tperiod = pot2.read_u16()
          tperiod=math.floor(raw_tperiod * 1000 / 65535 ) + 1				# and the internal oscillator frequency     
          led2.value(0)                                                                 
          count = count+1
          if (count>=max_count):
              count = 0
              div.value(1)
              led2.value(1)
              led2_Timer = Timer(period=1, mode=Timer.ONE_SHOT, callback=LED2_Off)
              if (sync==1):
                  out_on.deinit()
                  out_on.init(period=tperiod, mode=Timer.ONE_SHOT, callback=Out_Off_Handler)
                  out_off.deinit()
                  out_off=Timer(period=1, mode=Timer.ONE_SHOT, callback=Out_On_Handler)
                  osc = 0
                  out_clock.value(osc)
          interrupt_flag=0                                                 # reset the interrupt flag

    else:
        old3INPUT = old2INPUT
        old2INPUT = old1INPUT
        old1INPUT = oldINPUT
        oldINPUT = INPUT
        INPUT=clk_in.value()
        if((INPUT==1)and(oldINPUT==1)and(old1INPUT==1)and(old2INPUT==1)and(old3INPUT==1)):
            Q1 = 0
    if(sync_interrupt_flag==1):
        sync_interrupt_flag = 0
        if(sync==1):
            sync=0
            syncLED.value(sync)
        else:
            sync=1
            syncLED.value(sync)
        

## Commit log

2024-03-26 Rename Euclid+ Main Board Schematic.pdf to Operation/Euclid+ Main Board Schematic.pdf
2024-03-26 Rename Hardware/Euclid+ Front Panel.kicad_pro to Hardware/Front Panel/Euclid+ Front Panel.kicad_pro
2024-03-26 Rename Hardware/Euclid+ Main Board.kicad_pro to Hardware/Main Board/Euclid+ Main Board.kicad_pro
2024-03-26 Rename Hardware/Euclid+ Control Board.kicad_pro to Hardware/Control Board/Euclid+ Control Board.kicad_pro
2024-03-27 Rename Hardware/Main Board/Euclid Main Board.kicad_pro to Hardware/Main Board/v1 Main Board/Euclid Main Board.kicad_pro
2024-03-27 Rename Hardware/Main Board/Euclid Main Board.kicad_sch to Hardware/Main Board/v1 Main Board/Euclid Main Board.kicad_sch
    [Euclid Main Board.kicad_sch]
2024-03-27 Rename Hardware/Main Board/Euclid Main Board.kicad_pcb to Hardware/Main Board/v1 Main Board/Euclid Main Board.kicad_pcb
    [Euclid Main Board.kicad_pcb]
2024-03-27 Rename Hardware/Control Board/Euclid Control Board.kicad_pcb to Hardware/Control Board/v1 Control Board/Euclid Control Board.kicad_pcb
    [Euclid Control Board.kicad_pcb]
2024-03-27 Rename Hardware/Control Board/Euclid Control Board.kicad_pro to Hardware/Control Board/v1 Control Board/Euclid Control Board.kicad_pro
2024-03-27 Rename Hardware/Control Board/Euclid Control Board.kicad_sch to Hardware/Control Board/v1 Control Board/Euclid Control Board.kicad_sch
    [Euclid Control Board.kicad_sch]
2024-03-31 Rename Software Version/EuclidPlusPi.kicad_sch to Software Version/Platform/EuclidPlusPi.kicad_sch
    [EuclidPlusPi.kicad_sch]
2024-03-31 Rename Software Version/EuclidPlusPi.kicad_pro to Software Version/Platform/EuclidPlusPi.kicad_pro
2024-03-31 Rename Software Version/EuclidPlusPi.kicad_pcb to Software Version/Platform/EuclidPlusPi.kicad_pcb
    [EuclidPlusPi.kicad_pcb]
2024-03-31 Rename Software Version/EUCLID+ Pi Prototype.png to Software Version/Platform/EUCLID+ Pi Prototype.png
2024-03-31 Rename Software Version/EUCLID+ Pi Pin Allocation.png to Software Version/Platform/EUCLID+ Pi Pin Allocation.png

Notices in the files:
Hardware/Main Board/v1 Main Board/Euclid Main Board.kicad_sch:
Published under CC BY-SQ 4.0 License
